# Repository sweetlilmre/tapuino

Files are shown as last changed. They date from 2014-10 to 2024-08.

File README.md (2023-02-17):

# Tapuino

This project is now in maintanence mode and has been superseeded by the [Tapuino Next](https://github.com/sweetlilmre/TapuinoNext)

However amazing people keep building this version and adding value (see the [3D printable enclosure below](#3d-printable-enclosure))

Limited support can be found in the following Amibay forum [Amibay](https://www.amibay.com/threads/tapuino-the-20-c64-tape-emulator.64874)

## The $20 C64 Tape Emulator

Details can be found on my blog: http://www.sweetlilmre.com

The FAQ and other docs can be found on the wiki: https://github.com/sweetlilmre/tapuino/wiki

A really nice board design can be found here: https://github.com/arananet/tapuinomini1.03

And a write up here: http://arananet-net.kinja.com/tapuino-1-03-mejorando-el-tapuino-mini-1788202676

These schematics are also provided in the "layout" folder as a convenience. 

Portions of this code are copyright by their respective owners:

 * PetitFatfs: Chan: http://elm-chan.org/fsw/ff/00index_p.html
 * I2C code: Peter Fleury <pfleury@gmx.ch>  http://jump.to/fleury
 * LCD code: conversion of the Arduino code apparently by DFRobot? (converted to C by me)

## 3D printable enclosure
by @fabriziofiorucci

A [3D printable enclosure](CAD) designed with Fusion 360 is available for download as .stl files

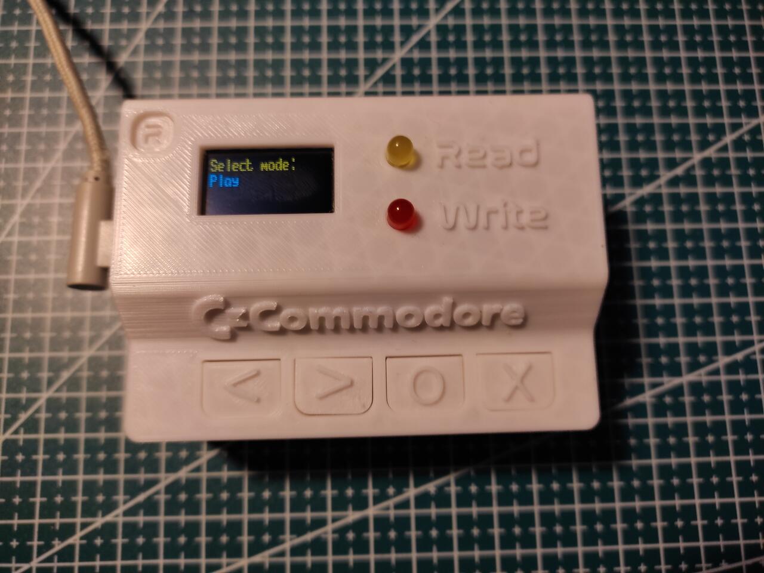
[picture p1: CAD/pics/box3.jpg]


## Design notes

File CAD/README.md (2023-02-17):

Tapuino 3D printable enclosure
==============================

This is a 3D printable enclosure designed with Fusion 360. It can be printed using PLA using:

- 3 walls
- 0.1mm layer height
- Supports for the top section and the C=64 connector lid



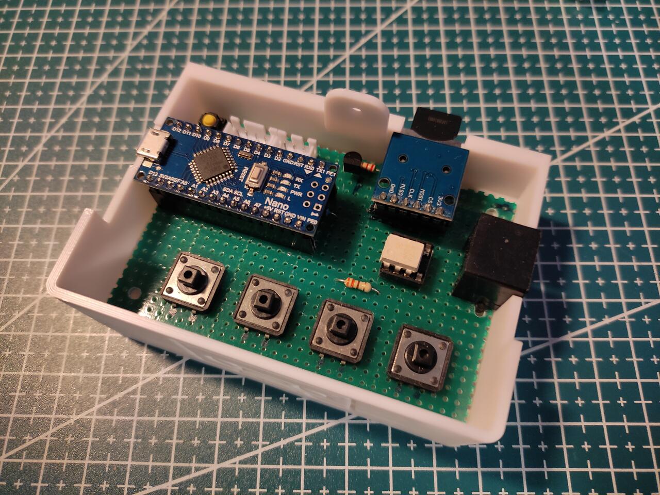
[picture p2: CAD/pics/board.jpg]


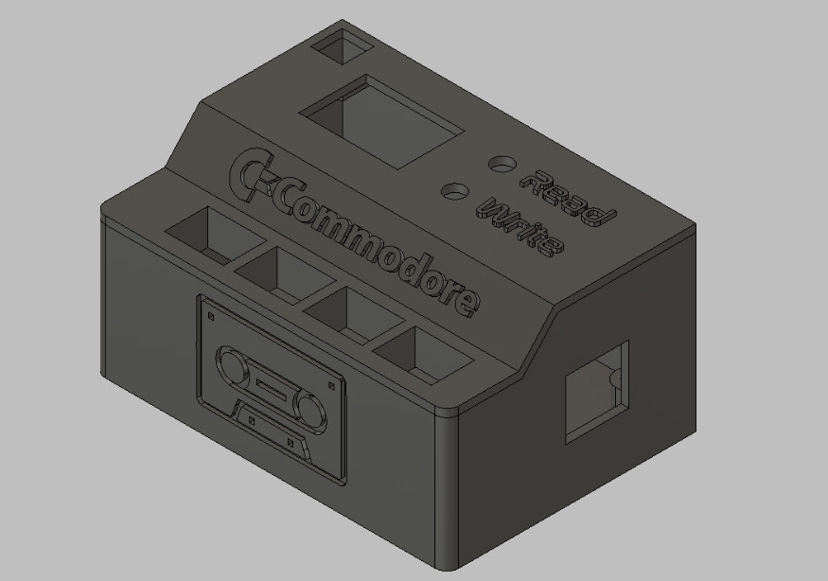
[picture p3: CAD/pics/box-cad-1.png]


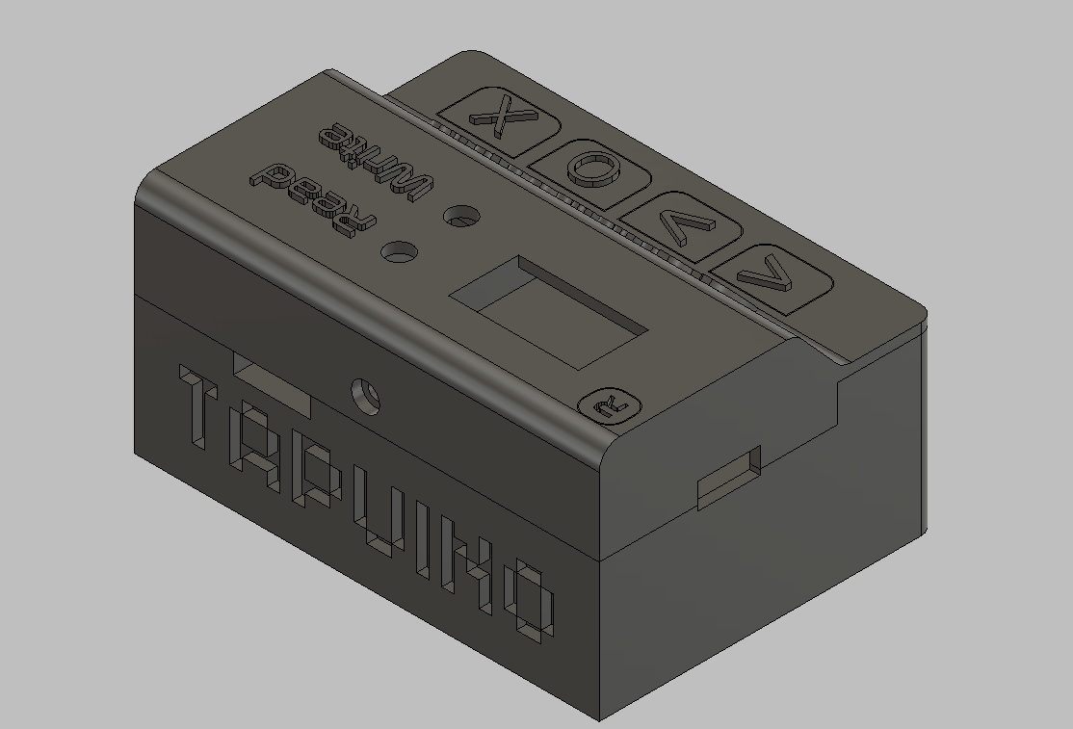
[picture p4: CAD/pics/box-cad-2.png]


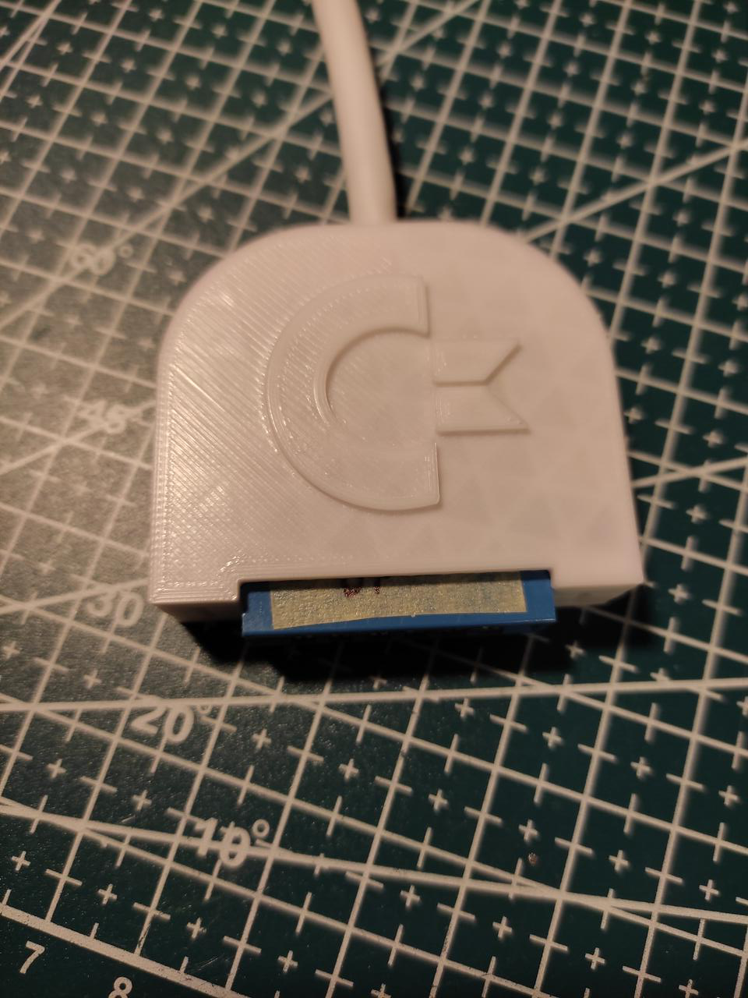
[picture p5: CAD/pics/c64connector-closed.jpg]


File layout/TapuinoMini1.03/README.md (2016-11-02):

# tapuinomini1.03

TapuninoMini 1.03 based on the design of OzayTuray - Original design by Peter Edwards ( sweetlilmre ).

A redesigned version of the Tapuinomini with built in buttons and connector on the PCB.

A step by step build process can be found on my blog:
http://arananet-net.kinja.com/tapuino-1-03-mejorando-el-tapuino-mini-1788202676

2016 -@edu_arana

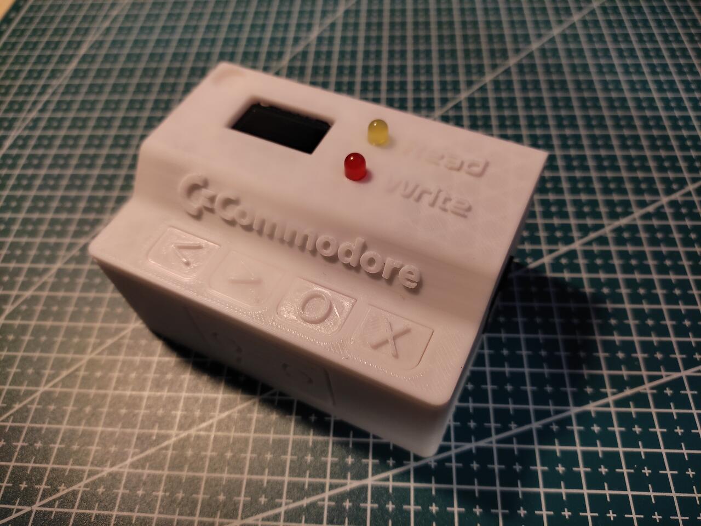
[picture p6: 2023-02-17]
CAD/pics/box1.jpg

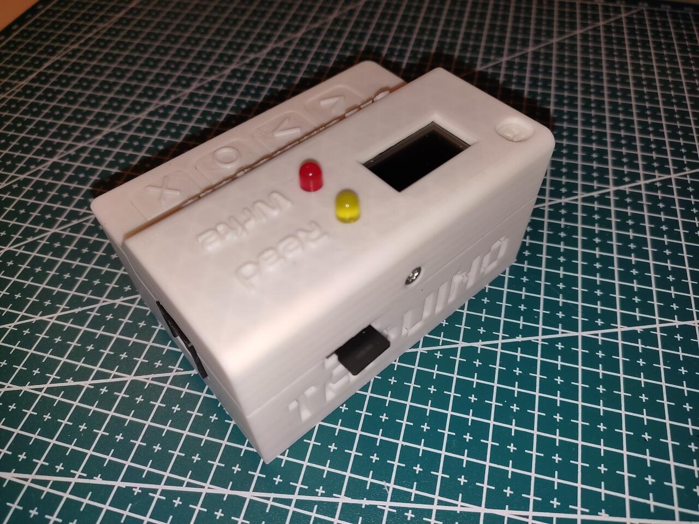
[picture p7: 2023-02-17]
CAD/pics/box2.jpg

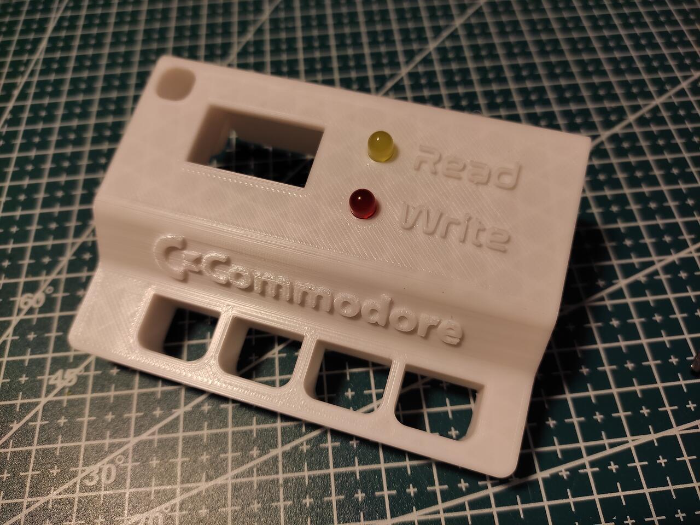
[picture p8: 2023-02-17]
CAD/pics/top.jpg

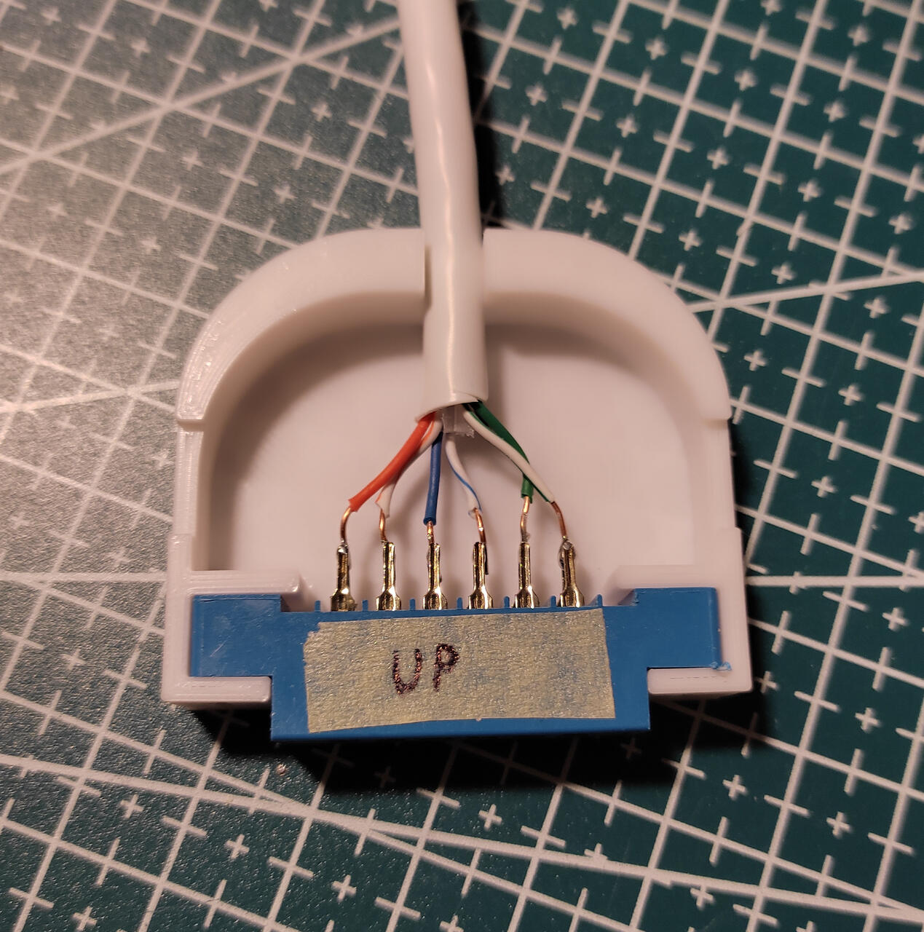
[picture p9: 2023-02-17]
CAD/pics/c64connector-open.jpg

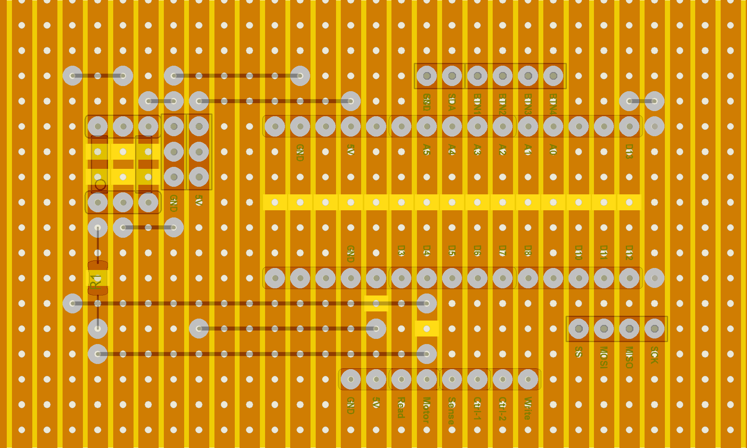
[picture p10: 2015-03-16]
layout/tapuino-main-bottom-r2.png

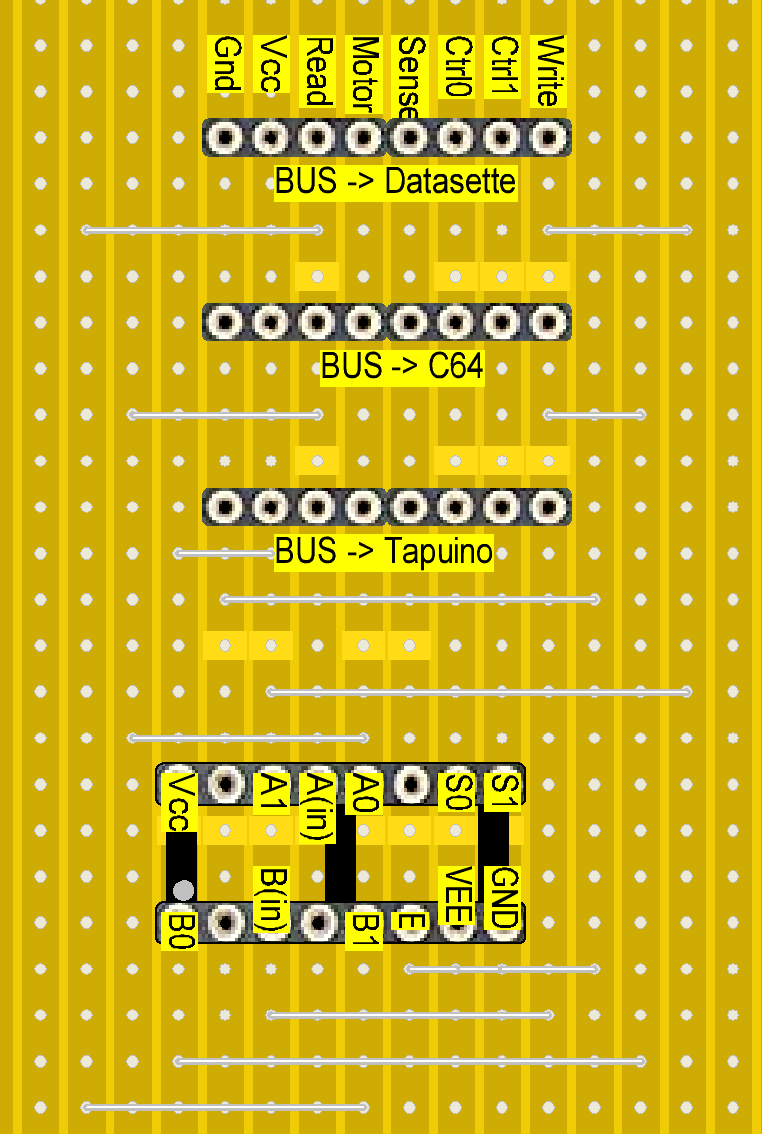
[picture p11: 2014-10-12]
layout/tapuino-mux-board-r2.png

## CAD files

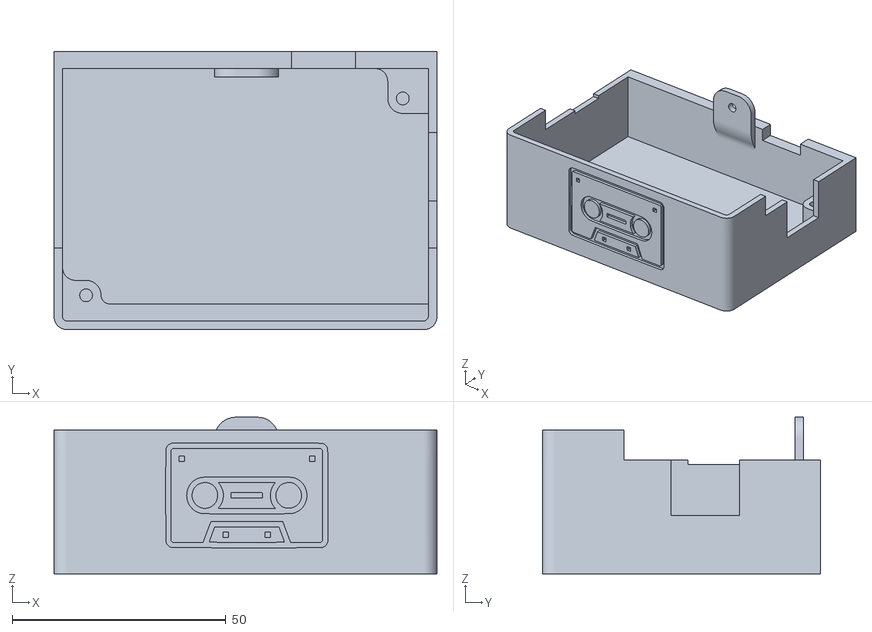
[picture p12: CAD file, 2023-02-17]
CAD/Main body.stl
89.5 x 65.0 x 36.6

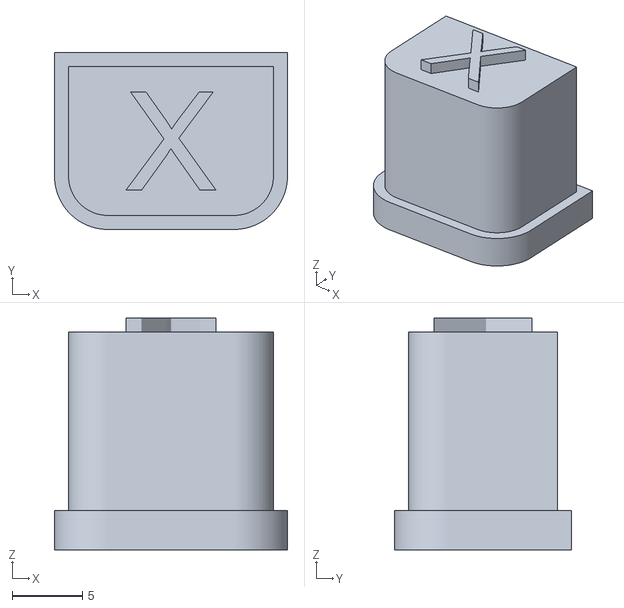
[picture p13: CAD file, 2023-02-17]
CAD/Key 4 - Cancel.stl
16.6 x 12.6 x 16.5

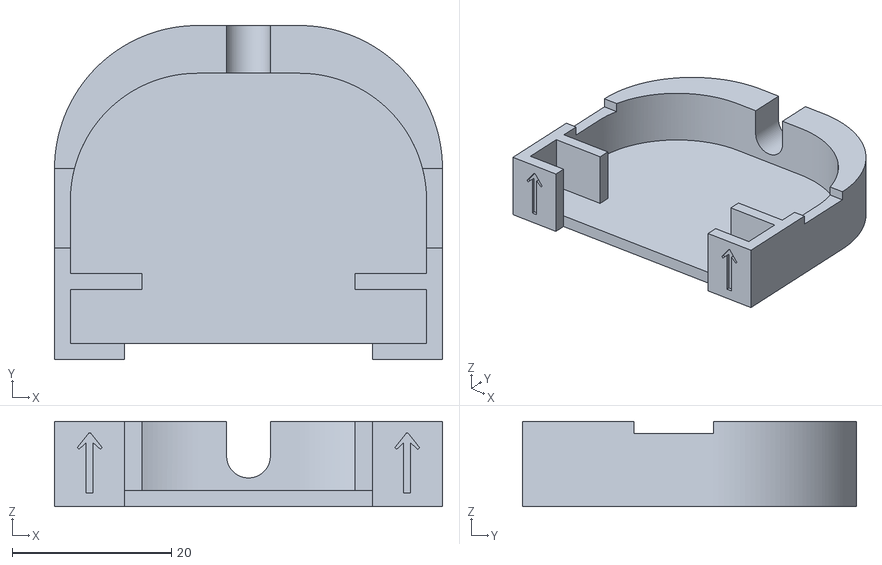
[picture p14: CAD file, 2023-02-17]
CAD/C=64 Datassette connector - base.stl
48.8 x 42.0 x 10.7

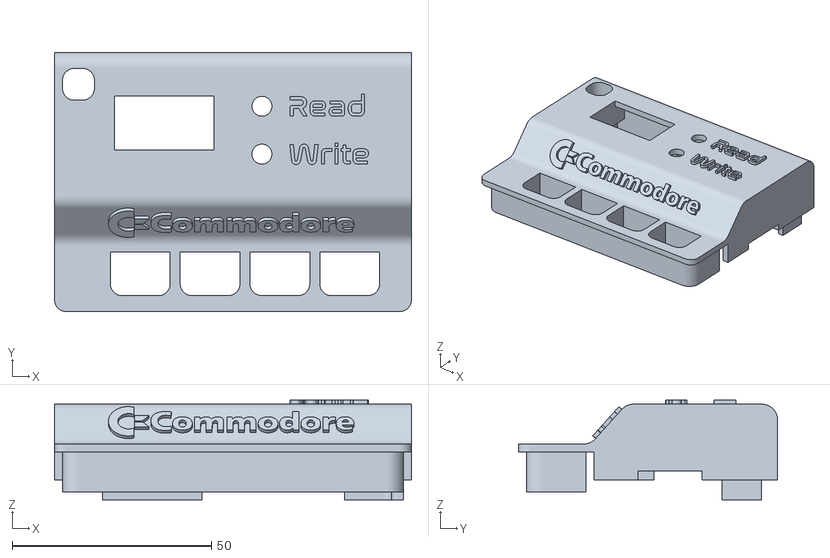
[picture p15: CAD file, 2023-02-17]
CAD/Top section.stl
89.5 x 65.0 x 25.0

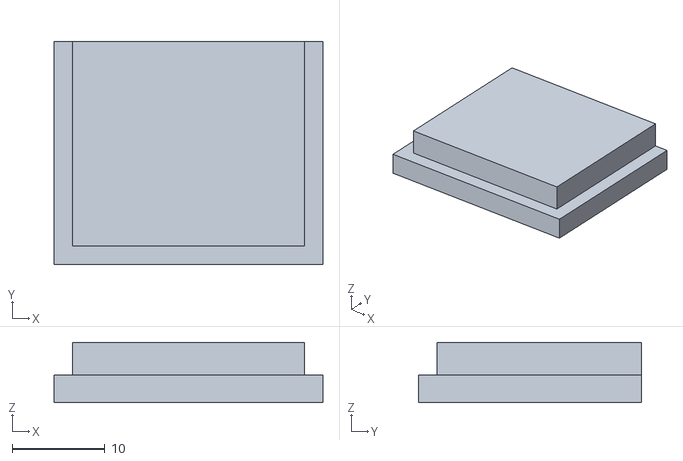
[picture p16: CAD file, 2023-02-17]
CAD/Display lid.stl
29.0 x 24.0 x 6.50

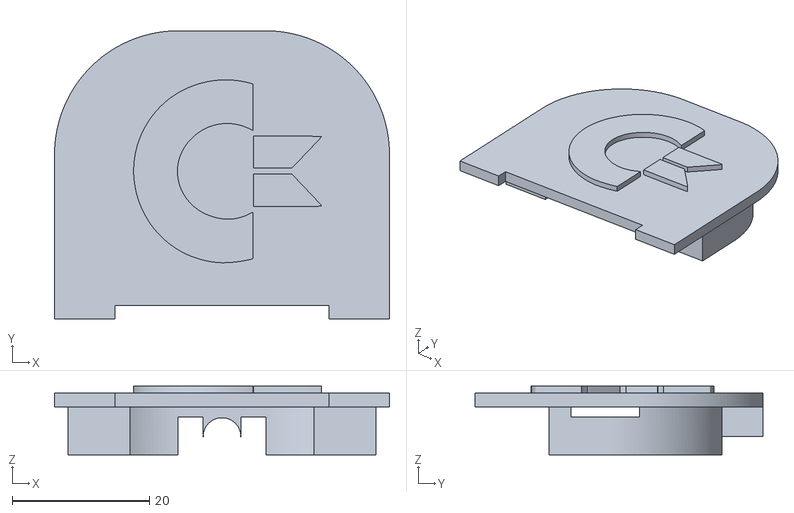
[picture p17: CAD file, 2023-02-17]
CAD/C=64 Datassette connector - lid.stl
48.8 x 42.0 x 10.00

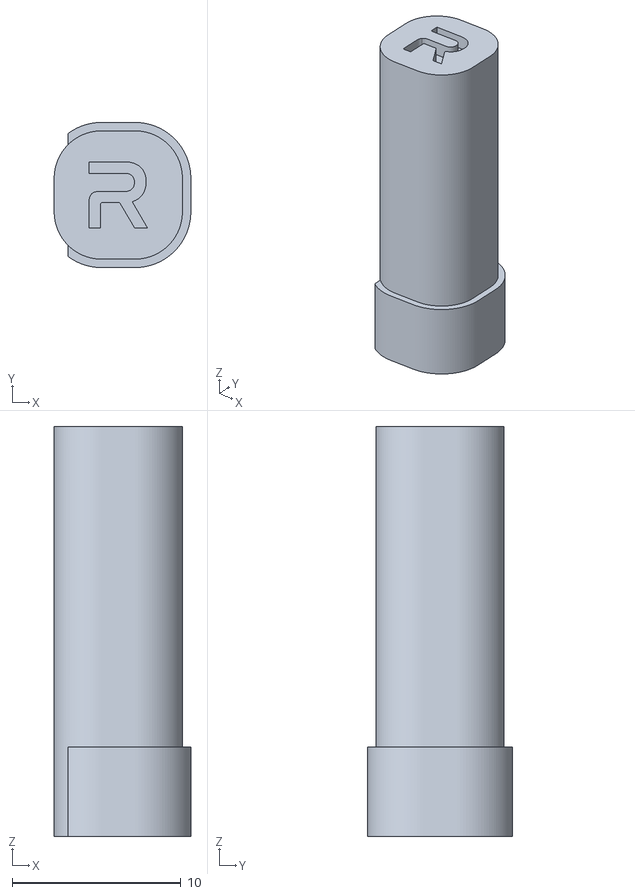
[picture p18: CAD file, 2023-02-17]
CAD/Reset button.stl
8.10 x 8.60 x 24.3

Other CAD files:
CAD/Key 1 - Left.stl
CAD/Key 3 - Select.stl
CAD/Key 2 - Right.stl

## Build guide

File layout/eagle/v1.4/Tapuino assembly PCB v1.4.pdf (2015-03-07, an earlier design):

# ASSEMBLY GUIDE FOR TAPUINO PCB V1.4 in PP9 BOX

v1.0

# BY spcbm

Thanks to all for your confidence in the Project, specially to sweetlilmre.

# PLEASE BE EXTREMLY CAREFUL TO AVOID

INJURY.

This is how I did the assembly, you may have a better way to do, just use it as a help.

Before starting, this PCB has the holes 2.8mm diameter, so you may need to make the holes 3mm for standard M3 screws and standoffs. If you plan to use the recommended PP9 box you will need to do the following:

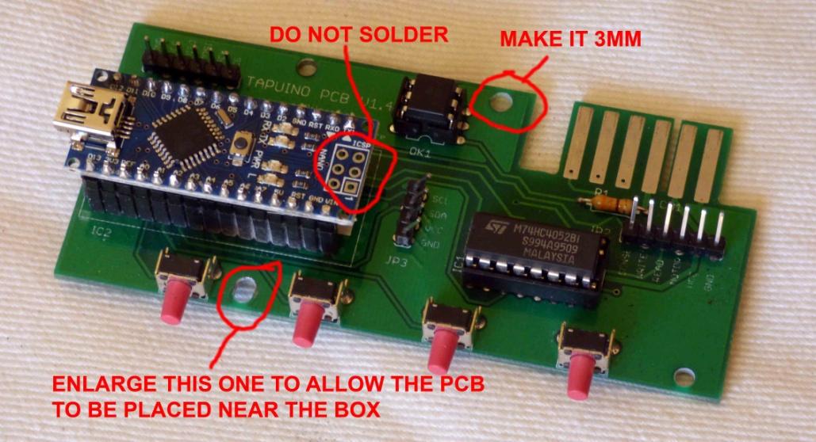
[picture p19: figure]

Solder all the components to PCB. Be carefull to align the buttons.

Do not solder the 6 pin header on Arduino or it will touch the LCD later.

If possible do not use socket for it, you will have more room for LCD and cables.

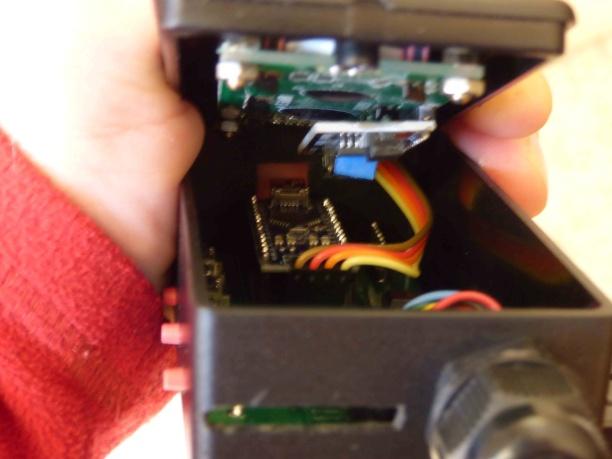
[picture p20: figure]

Drill the holes for LCD on the cover, you can use the template.

3mm drill for the 4 screws and 6mm drill for the rectangular hole.

I used wood drill that is OK for plastic also.

Verify your LCD to have the same layout before drilling. You may want to place LCD a little up instead of centered to avoid the I2c board touching the arduino.

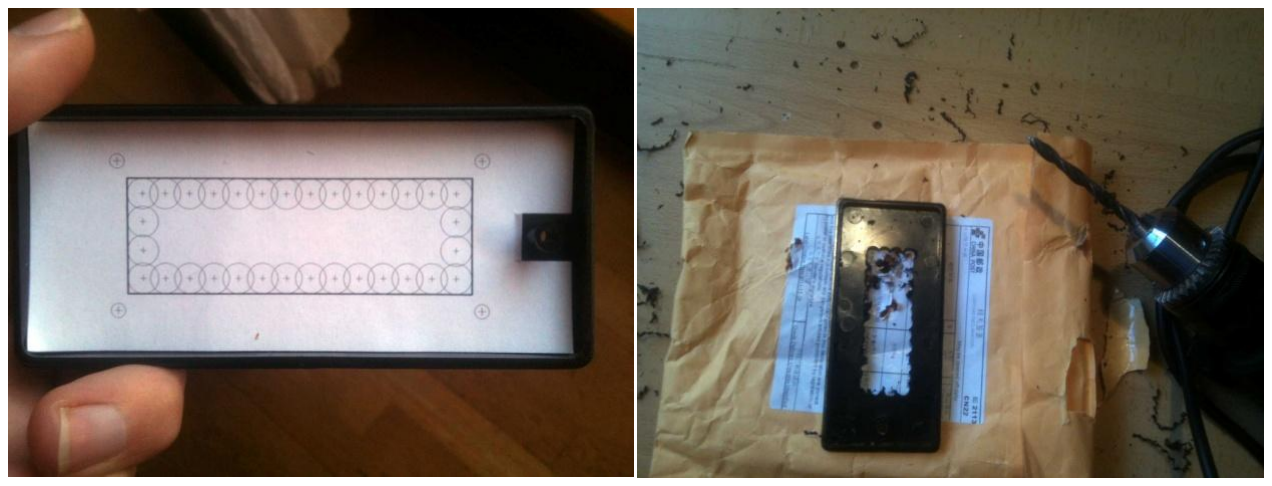
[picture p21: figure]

After a bit of sanding

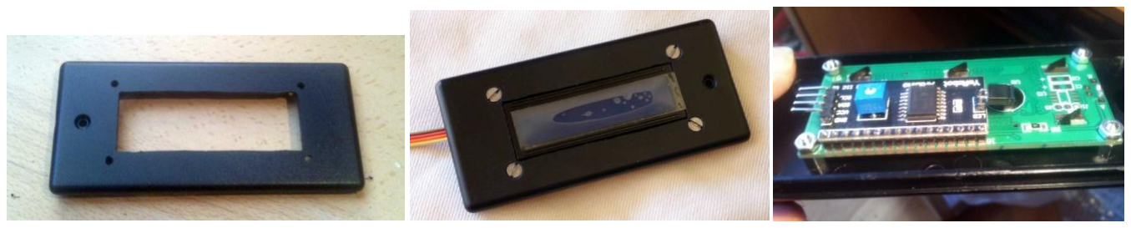
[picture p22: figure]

You need to countersink the 4 holes, use a 6mm drill (not for wood now)

If you do not have a stationary drill, do it with your hands, otherwise you may make a 6mm drill.

Using 4 standoffs M3 male-female, nuts and very short screws and you are done with LCD.

Time to make drills for the buttons, use the template and a 4 or 4.5mm drill.

Check carefully allignament before drilling.

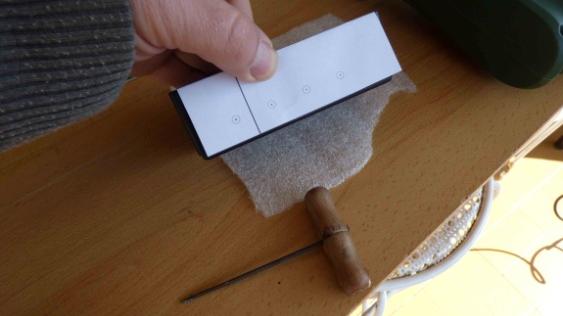
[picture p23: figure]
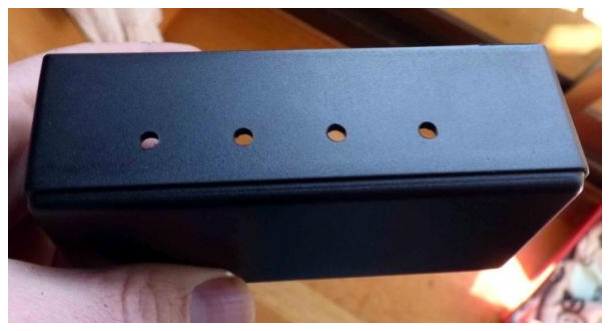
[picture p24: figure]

The PCB should fit now inside the box, put the 3mm sheet metal screw thread | near the first
button and thread it into the plastic standoff of the box. Then mark the hole position for a new standoff you need to add.

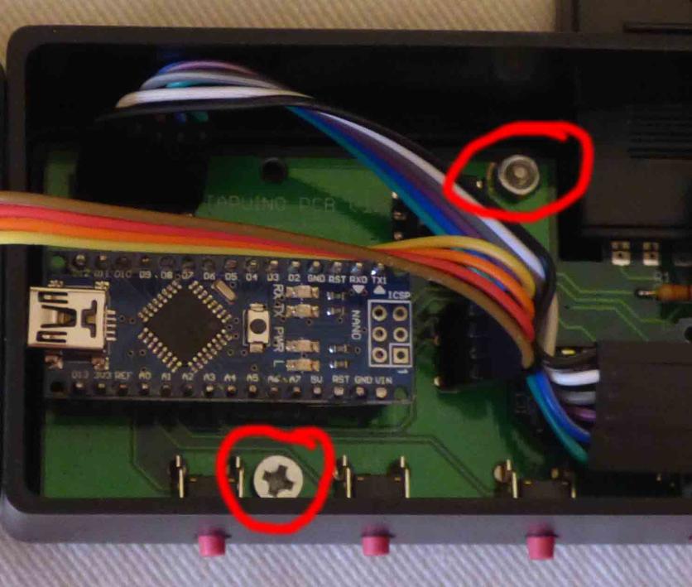
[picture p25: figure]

As the standard standoffs are 5mm just add 2 washers to reach 6mm that is the height of the plastic one of the box, just to keep PCB horizontally.

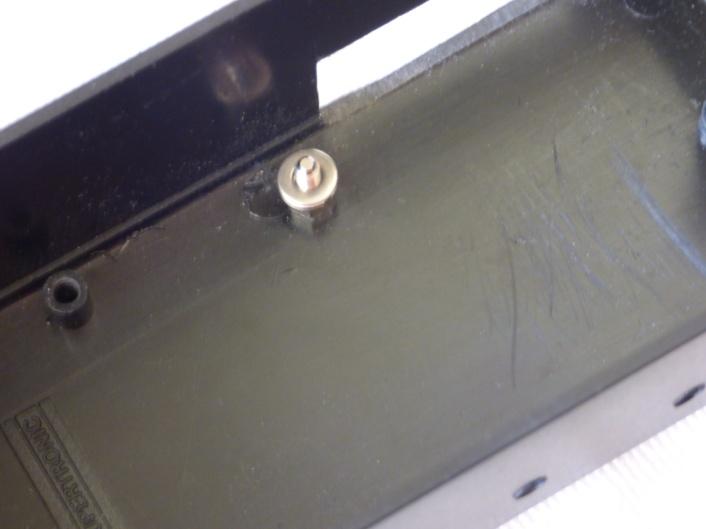
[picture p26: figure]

Now make the holes for datassette connector and USB . Always check before drilling.

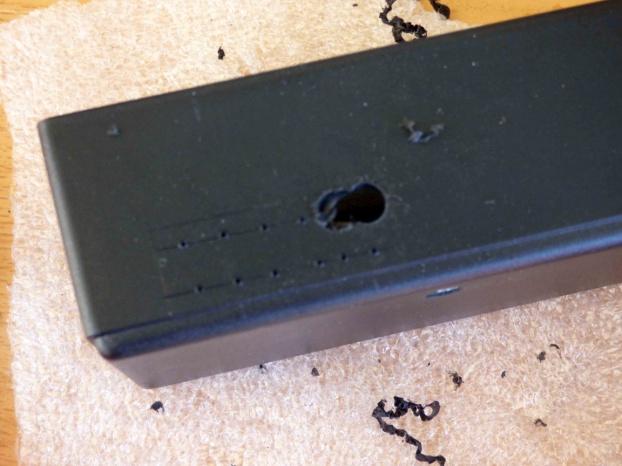
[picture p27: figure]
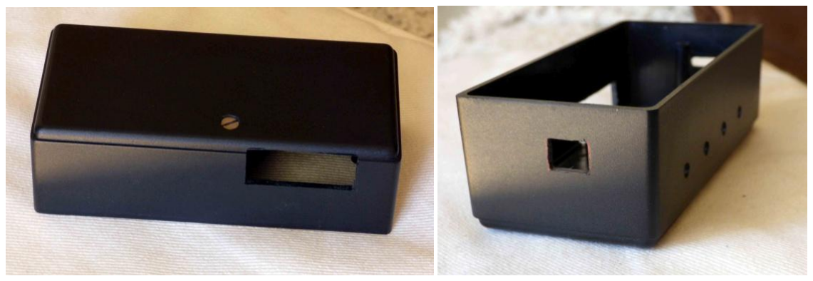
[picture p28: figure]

I’ve found this place to put micro SD shield. You need to make a small notch in the PCB

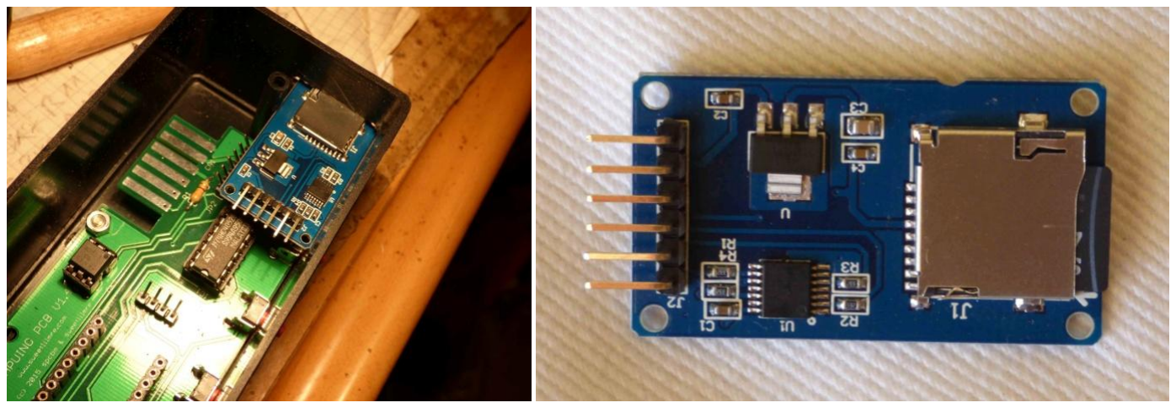
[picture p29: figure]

Verify that you can insert and extract SD card before making the notch.

Then you can make the hole, I used 3mm drills for this.

You can put a piece of plastic under SD shield to avoid shortcircuits.

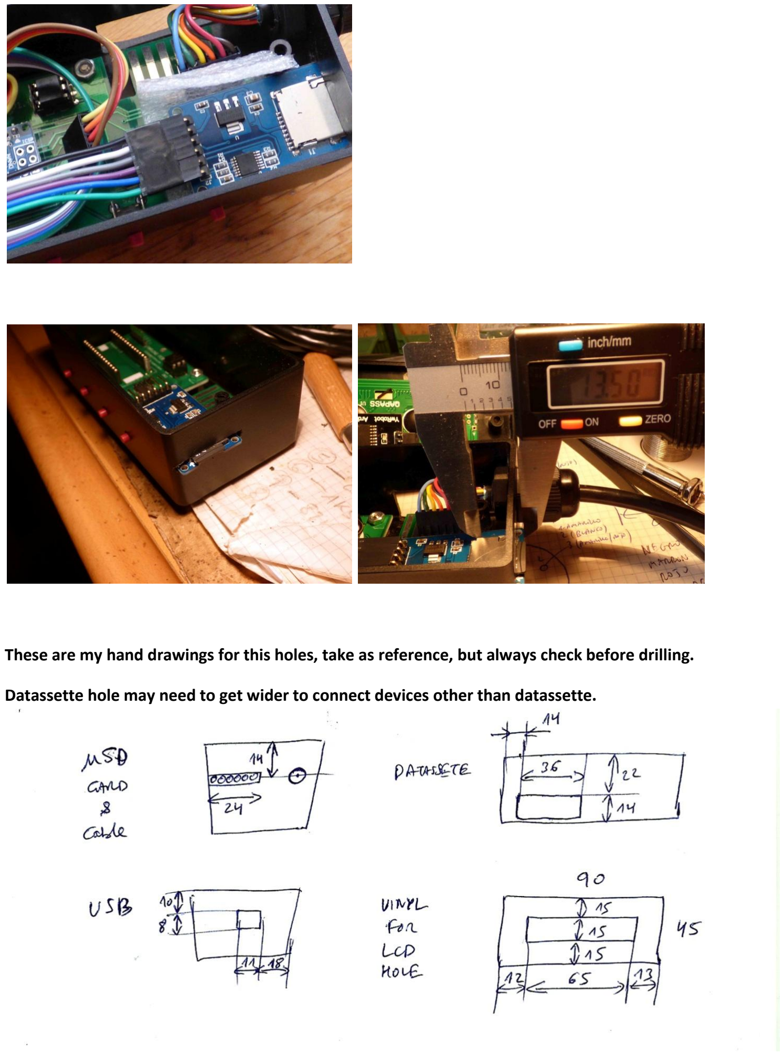
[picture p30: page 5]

These are my hand drawings for this holes, take as reference, but always check before drilling.

Datassette hole may need to get wider to connect devices other than datassette.

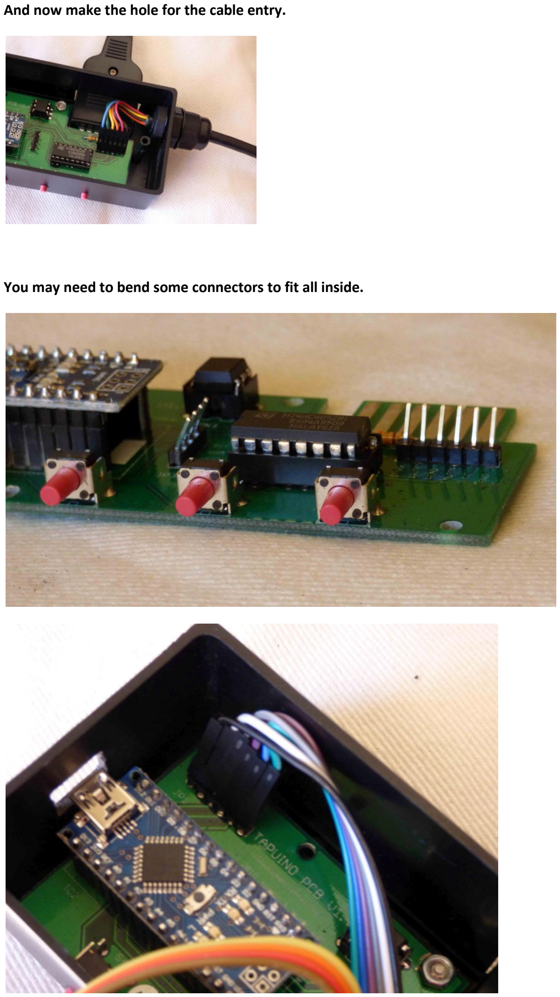
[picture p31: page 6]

And now make the hole for the cable entry.

You may need to bend some connectors to fit all inside.

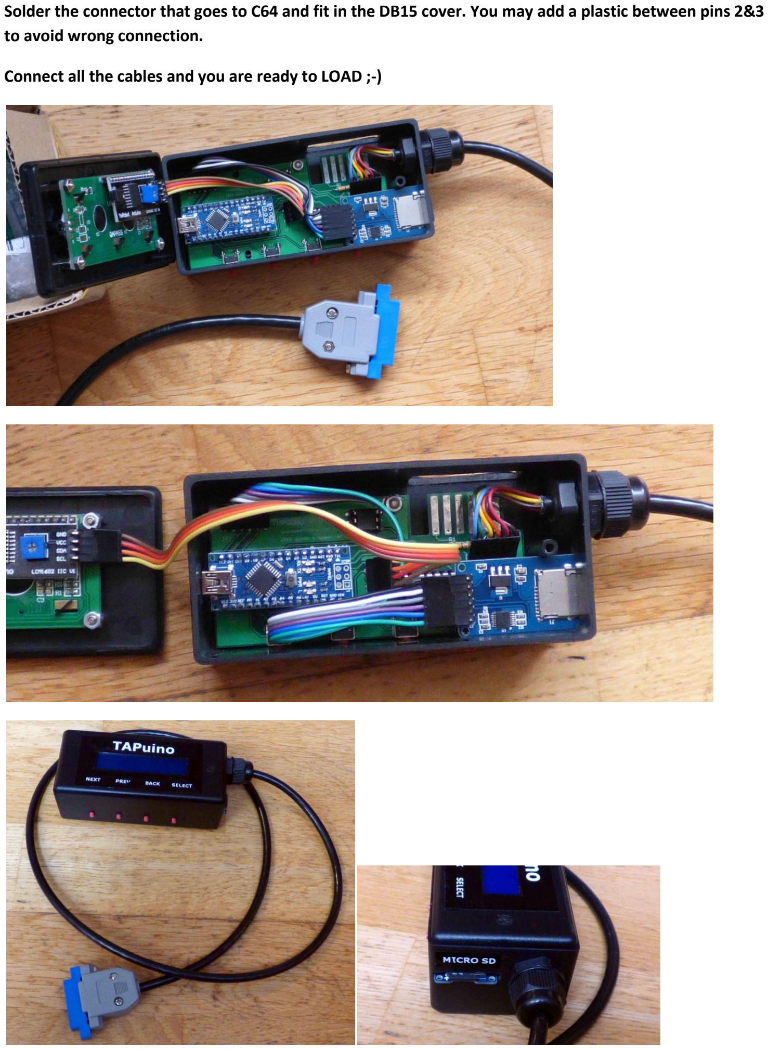
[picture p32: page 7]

Solder the connector that goes to C64 and fit in the DB15 cover. You may add a plastic between pins 2&3 to avoid wrong connection.

Connect all the cables and you are ready to LOAD ;-)

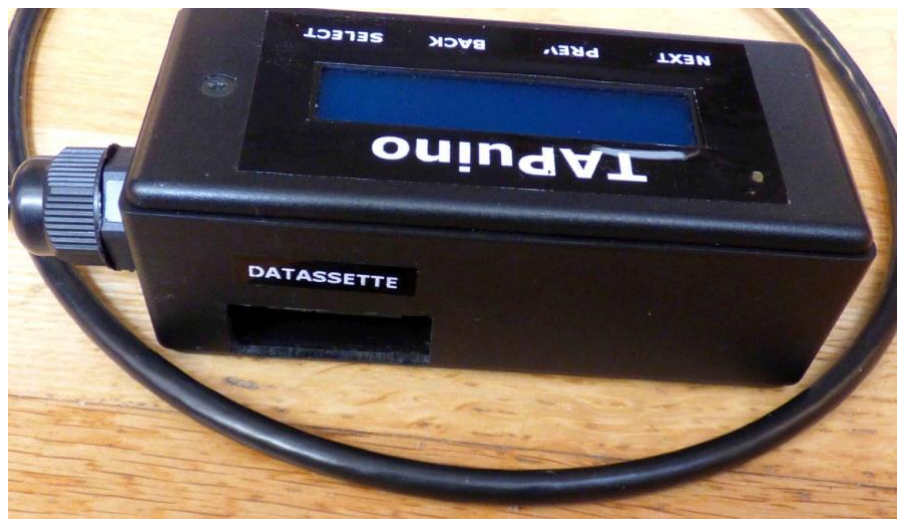
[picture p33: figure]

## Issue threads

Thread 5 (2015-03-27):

Recording does not work on an SD card with no files or folders

sweetlilmre, 2015-03-27:
Part of the init code checks to see that there are a non-zero number of files or folders on the SD card and fails if this is not the case. This prevents recording on new cards.

sweetlilmre, 2015-03-27:
Fixed in commit: 65e503846d91745694a79337717c09b2bd39a0f7

Closed 2015-03-27.

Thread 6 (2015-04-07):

6 buttons

Sven1973, 2015-04-07:
At this moment are only 4 buttons implemented in software. For using a original housing of 1531 it will be nice to implement 2 more buttons.
RECORD for switching/toggeling recordmodes
EJECT for toggeling directories (as example)

juri74, 2015-04-16:
i would not add more buttons because there are already lot of tapuino players that would have to redo all work, i will add support for 6 buttons in a different manner:

2 buttons pushed togheter; example: play and stop pushed togheter will ats like a eject, unloading tape and put you on the root of sd card
play + forward acts like record.. so you can put more microswitches but mantaining the compatibility for 4 buttons layout.
one interesting function however would be PAUSE, since there are lot of tapes with multiple programs on it, in this way could be possible to pause the tape, reset c64, type load"" and finally unpause the tape to continue loading...
this could be implemented with the "select" button: pressing it during tape loading will put pause on, pressing again will put pause off.

Sven1973, 2015-04-17:
yes, your solution with two Buttons pushed together sounds plausible.
And it would work for me too, just a question of wiring...
thats a good idea !

sweetlilmre, 2021-09-13:
closed stale.

Closed 2021-09-13.

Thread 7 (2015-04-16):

Save led, piezo to "listen to" the tape

juri74, 2015-04-16:
Could be possible to implement:
1) a red led that will lit when saving in progress?
2) a piezo that play the music? :D for ability to listen loading/saving maybe turnable on/off in Options menu ;)
i splitted the pause from led & piezo, since there is an hardware solution is better use it to save program space.. however a led connected to D13 (if isn't used for other things) could be useful and shouldn't use much program memory i think (D13 is already connected to a led on almost all arduinos) :)

sweetlilmre, 2015-04-17:
There are hardware solutions available for something similar to the piezo via ozayturay's board (provides LEDs that are transistor driven for SAVE / LOAD).
Please could you break this up into separate issues? The save LED could be handled fairly easily via code (just add an output) etc. so tracking these separately is better.

sweetlilmre, 2015-05-24:
The save LED function will be added with the release of the 1.7 hardware and controlled via software, I'm just waiting for the boards so that I can verify this.
The piezo switching is another story and would require hard ware support so I don't think this is going to happen.

juri74, 2015-05-25:
Thank you for update, i have an idea on how doing piezo support with minimal effort, i think arduino should provide an "activation signal" then it will be ANDed with the tape read or tape write signal, finally the output pin of the AND chip will drive a piezo. i have to wait the 1.7 board too and some parts for testing :) i lost track of available pins, is there one free? thanks
Juri

sweetlilmre, 2015-08-16:
Save LED support has been added to the code base, piezo is hardware supported on 1.7.

Closed 2015-08-16.

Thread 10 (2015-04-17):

Pause function

juri74, 2015-04-17:
Could be possible to implement a pause button? example: using the "select" button during tape play, pressing it will pause tape and pressing it again will unpause tape.
this would be useful with tapes that have more programs/games in it

sweetlilmre, 2015-05-24:
How common is this? A higher priority would be proper seek control for multipart games, which would probably provide you with what you needed for this feature.

sweetlilmre, 2015-05-25:
I've added experimental support for this in the pause-func branch. Test and I'll think about merging it into master as a temporary fix until proper play control is added

sweetlilmre, 2015-06-05:
This is now in master

Closed 2015-06-05.

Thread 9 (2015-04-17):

C16 / Plus 4 halfwave playback support

sweetlilmre, 2015-04-17:
Adding support for format 2 (halfwave) TAP playback would extend the reach of the Tapuino to these platforms.

juri74, 2015-04-17:
i tested some v2 (and v1) c16 tap with tapuino without success. when i press select when displaying a tap file name nothing happens (if the file name is scrolling on display the scroll position is resetted to beginning of text every time i press select button)

sweetlilmre, 2015-04-17:
How recent is the code you have flashed? There was a bug where the C16 TAP file would have been considered invalid but the error would not have been displayed making it look like nothing had happened. This code has changed and C16 support was added for headers a few versions back.
Can you confirm or flash the latest and try again?

juri74, 2015-04-18:
hello! updated to the most recent version and now it recognize some files (some give INVALID TAP)
i sent you a report email with attached a zip file containing the TAP files i tested.

sweetlilmre, 2015-04-21:
Hi. I've updated the source with some fixes, please test when you are back in town.

juri74, 2015-04-21:
hello
i will test asap :D

Il 21/04/2015 16:47, sweetlilmre ha scritto:
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

---
Questa e-mail è stata controllata per individuare virus con Avast antivirus.
http://www.avast.com

juri74, 2015-04-25:
I made further test with updated firmware, actually i had a problem only with one file on 19 files tested, i'm going on testing, but it does appear the last firmware update really fixed lot of tap loading problems :)

sweetlilmre, 2015-05-24:
This code is in now and I have a C16 on order so I will hopefully be able to look into this in more detail once I have the machine :)

sweetlilmre, 2021-09-13:
closed

Closed 2021-09-13.

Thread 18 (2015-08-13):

Recordings are finalized when motor stops

Quagliarulo, 2015-08-13:
Hello, I have a proposal. Tapuino shouldn't finalize a recording when the motor is turned off. It should just wait for either the motor to be started again or the user to press "stop". I'm playing with the Freeload mastering tool. It loads each file from disk and then stores it on tape. But it doesn't work with Tapuino, because when the program stops the motor and reads from disk, the recording is finalized.

sweetlilmre, 2015-08-16:
I have added a branch to test this as a new feature.
Under the options menu there is an "Auto Finalize" option. If this is set to zero then the recording will continue until the ABORT button is pressed. Please test and let me know if this addresses the issue.

Quagliarulo, 2015-08-17:
Hello and thank you for your time. Your modification addresses the issue. Here's a freeload game mastered with Tapuino:
https://drive.google.com/file/d/0Bzow0Exbi92AeW5IQ2RHcUFyNnc/view?usp=sharing

Some thoughts:
- A couple of times I had lockups while browsing through the menus, with a strange string:
https://drive.google.com/file/d/0Bzow0Exbi92AeXdZRlJjUzl5Ylk/view?usp=sharing
I guess this might be due to some "unexpected" button presses I made (I connected my button panel incorrectly and wouldn't bother to fix it). I'll try to replicate it.
- "Auto di finalizzazione" should become "Auto finalizza" (how do I know? I'm Italian :)
- I think the spinning character shouldn't spin when the motor is off

Quagliarulo, 2015-08-17:
I just noticed there are very long pauses between freeload blocks. This doesn't happen with Vice (no pauses at all in that case). Gotta try with real tape.

Quagliarulo, 2015-08-17:
Real tape mastered and dumped with MTAP. Tapclean says pauses between Freelod blocks are either 1.0556 or 1.0759 seconds, so I'm afraid something doesn't work.

sweetlilmre, 2015-08-19:
I've added another commit to try and address the pausing issue as well as the menu bug introduced by the previous commit. Please test!

sweetlilmre, 2021-09-13:
closed due to inactivity

Closed 2021-09-13.

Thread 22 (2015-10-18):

Datassette calibration function

Quagliarulo, 2015-10-18:
Very simple: a function which samples pulses and shows a percentage or something like that. It may work like this:
- Capture all the pulses occurring in a given time frame and store them only once each. If the number of unique pulses reaches a given maximum, assume no data or very bad alignment.
- See how many different pulses we got. In a hypothetical perfectly aligned tape, we wouldn't get less than 2 or 3 pulselengths in total. The more pulselengths, the worse the alignment. So at this point, we may show a percentage or some description such as "Good", "Bad", and so on.

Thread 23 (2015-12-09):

Rotary Encoder

Cino2424, 2015-12-09:
I would prefer a rotary encoder support instead of 4 buttons.
It would be easier to create a smaller case or to build it into the c64 case himself.

sweetlilmre, 2016-06-13:
Support for this feature has been added

Closed 2016-06-13.

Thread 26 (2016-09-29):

Compiler warnings and NL language

Squirrel61, 2016-09-29:
Recently, I brought new life into an old love and acquired a used C64. Of course, I wanted to know what could be done with such an old system using new technology and discovered your Tapuino project.

Currently I'm still waiting for some of the parts needed, but I already had an Arduino Nano V3 which I programmed with the Tapuino firmware.

When compiling with the current Arduino IDE 1.6.12, 4 warnings where issued. I don't know if this is a result of compiler changes in the recent IDE or if they already where present when you created the project. I also don't know, when the warnings already where present when you created the project, if they where left there on purpose. However, they're easy to clear.

This is the list of warnings:

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

To correct, I changed tapuino.h as follows:
`#ifndef TAPUINO_H
# define TAPUINO_H
# include "ff.h"

void tapuino_run();
void record_file(char\* pfile_name);
int play_file(FILINFO\* pfile_info);
uint32_t get_timer_tick();
void save_eeprom_data();

extern volatile uint8_t g_invert_signal;
extern volatile uint16_t g_ticker_rate;
extern volatile uint16_t g_ticker_hold_rate;
extern volatile uint16_t g_key_repeat_next;
extern volatile uint16_t g_rec_finalize_time;
extern volatile uint8_t g_rec_auto_finalize;
extern uint8_t g_machine_type;
extern uint8_t g_video_mode;
extern volatile uint8_t g_is_paused;
# endif`

This makes the project compile without warnings. However, since I've not been able to test it (still waiting for some parts), I don't know if I possibly broke something.

Furthermore, I've also created a Dutch menu language file. But have to check on the working hardware if all messages are meaningful before I'll share them.

sweetlilmre, 2016-09-29:
Good catch. Seems I missed that in the header, there should be no untoward issue with fixing this that I can think of. Please submit a pull request to fix this if you could and when you have finished with the Dutch translation, submit another and I will action.

Squirrel61, 2016-10-04:
I tried to submit a pull request but actually, I have no idea if I succeeded. Github is totally new to me so I might have done something wrong. Excuse me if I screwed up the main project ;)

Closed 2017-12-25.

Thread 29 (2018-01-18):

Porting to Mega 2560 : problem after "found" message

dashiad, 2018-01-18:
I'm mixing your code with some iec code i've developed, to have both tape and disk support.
As the code for the disk may grow (a lot), and i've added a touchscreen, i've chosen a mega 2560 as target device.
But i'm getting a bit stuck with a problem: the load starts ok, but, after the "found xxx" message appears, looks like somewhere is not detecting the play button as pressed anymore: after the "found" message, i get a "LOADING" and then,again, "PRESS PLAY ON TAPE".

Any idea of what may be happening? (I ported the code to a mega 1280 without problems)
My pin assignment is (even pins from 35 to 41):

// port definitions, change for different wiring
#define SENSE_PORT          PORTG
#define SENSE_DDR           DDRG
#define SENSE_PIN           0
#define SENSE_ON()          SENSE_PORT &= ~_BV(SENSE_PIN)
#define SENSE_OFF()         SENSE_PORT |=  _BV(SENSE_PIN)

#define TAPE_READ_PORT      PORTC
#define TAPE_READ_DDR       DDRC
#define TAPE_READ_PIN       0
#define TAPE_READ_PINS      PINC
#define TAPE_READ_LOW()     TAPE_READ_PORT &= ~_BV(TAPE_READ_PIN)
#define TAPE_READ_HIGH()    TAPE_READ_PORT |=  _BV(TAPE_READ_PIN)

#define TAPE_WRITE_PORT     PORTG
#define TAPE_WRITE_DDR      DDRG
#define TAPE_WRITE_PINS     PING
#define TAPE_WRITE_PIN      2

#define MOTOR_PORT          PORTC
#define MOTOR_DDR           DDRC
#define MOTOR_PIN           2
#define MOTOR_PINS          PINC
#define MOTOR_IS_OFF()      (MOTOR_PINS & _BV(MOTOR_PIN))

juri74, 2018-01-19:
that's very curious.
have you tried different taps? have you tried to load the same tap with a real datassette?
that sound very strange because as soon as "found" message appear, when you press space or commodore key even if you have stopped the datassette, the c64 should behave like if the play button is pressed (even if it isn't)

dashiad, 2018-01-19:
I've been debugging a bit more.
What i've found is : tapuino thinks the tape has finished
(g_tap_file_pos == g_tap_info.length) (line 225 of tapuino.c).
Looks like something is messing with the timer, maybe the lcd code. I'll try using timer 3 instead 1 to see if that helps.

But at least i've a hint about what is wrong with my code, (of course, it's not tapuino's fault), so i'm closing the issue. Thanks for your help!

Closed 2018-01-19.

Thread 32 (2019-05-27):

Low memory warnings

gwiorek, 2019-05-27:
Is this normal?  First time working with the code part of tapunio and a bit rusty with the Arduino but seems to be a big possible issue should you have more the a few tape files to track.

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

Trying to reimage my mini as it jsut stopped working and trying to resurrect it as it looks like the nano may be still working but lost the software.

sweetlilmre, 2019-05-27:
This is fine, the sketch is just almost at max capacity for the nano.

gwiorek, 2019-05-27:
Thanks!  

-----Original Message-----
From: sweetlilmre <notifications@github.com>
To: sweetlilmre/tapuino <tapuino@noreply.github.com>
Cc: gwiorek <gwiorek@aol.com>; Author <author@noreply.github.com>
Sent: Mon, May 27, 2019 12:41 am
Subject: Re: [sweetlilmre/tapuino] Low memory warnings (#32)

This is fine, the sketch is just almost at max capacity for the nano.—
You are receiving this because you authored the thread.
Reply to this email directly, view it on GitHub, or mute the thread.

Closed 2019-05-27.

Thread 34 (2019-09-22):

The Max7219.h library

Therealjosephchrzempiec, 2019-09-22:
Hello i was looking at the code and say there is a Max7219.h in the arduino ino. But in your files you do not have have the libray there. I don't know that library either. I know the Max7219 chip is a input/output driver for leds. But yet somehow the code compiles with no problem even if i don't have that library. Strage!!

I never saw a code  compile with no errors with a missing library. Why is this?

Joseph

sweetlilmre, 2019-09-24:
Hi,

I don't see this in the .ino file?

Therealjosephchrzempiec, 2019-09-24:
I'm  sorry that was the sd2iec i was looking at my mistake.

sweetlilmre, 2019-09-24:
No worries :-)

Therealjosephchrzempiec, 2019-09-24:
I just tried tapuino for the first time tonight and went great
 I hand build my own becuase i cant afford to buy one. But it took me a while to figure out the wiring. Used a lot of jumper wires lol.

Closed 2019-09-24.

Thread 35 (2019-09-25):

Not a issue but I have a question

Therealjosephchrzempiec, 2019-09-25:
Hello you did a awesome Job on the tapuino for arduino. It works great, Thank you.  But i have a question have you looked into maybe doing the sd2iec? I know there out there  but not a arduino version.

Joseph

sweetlilmre, 2019-09-25:
The arduino doesn't have enough power to handle sd2iec.
I did look at it once. Better bet would be a cheap arm board

Therealjosephchrzempiec, 2019-09-25:
Hello thank you.  Is there a better way to get a message to you without taking up issues in here?

sweetlilmre, 2019-09-25:
Email? My username at Gmail.

Closed 2019-09-25.

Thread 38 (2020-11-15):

Possibe bug while reading the tape buffer?

dashiad, 2020-11-15:
Hello,
For a small project i'm working in, i want to refactor some code out of the interrupt handler, specially calculating the pulse lengths in the main loop. That would produce a mismatch between the number of bytes read from the file, and the number of pulses to fire, as "overflow" bytes need 4 bytes if the version is not 0.
So, theoretically,  to correctly convert  X bytes from the file to pulses, i need to be sure the buffer grows, if necessary, up to X+3 bytes, in case the last byte read is 0x00 (overflow byte), and version is not 0.
So i went to check how this is managed in tapuino, but (correct me if i'm wrong) looks like a fixed chunk of  FAT_BUF_SIZE bytes are read, and the isr code is supposing that, if a 0x00 byte is found, the other 3 bytes do exist in the buffer
```
 if (tap_data != 0) {
          g_pulse_length_save = tap_data * g_cycle_mult_8;
        } else {
          g_pulse_length_save =  (unsigned long) g_fat_buffer[g_read_index++];
          g_pulse_length_save |= ((unsigned long) g_fat_buffer[g_read_index++]) << 8;
          g_pulse_length_save |= ((unsigned long) g_fat_buffer[g_read_index++]) << 16;
         ...
   }
```
So, if a 0x00 byte is found at g_fat_buffer[FAT_BUF_SIZE-1], arent those lines accessing unitialized memory?

sweetlilmre, 2020-11-16:
I think you are correct. Amazingly this doesn't seem to have caused a problem in real life. Even more so as the potentially out of bound bytes are the most significant values of the timing signal and random data could really skew the value.
The issue for me is that the buffer swapping and handling is tightly coupled to the buffer size and would require significant rework to fix. I really need to rewrite this codebase at some point to use a more modern mcu like an ESP.

sweetlilmre, 2020-12-01:
On further reflection this isn't actually a problem :)
The buffer that the data is read from is a 256 byte buffer, indexed by a byte-wide variable (g_read_index).
Think of the buffer as two 128 byte buffers joined together.
As the longer pulse lengths are computed 1 byte at a time, if the index is 255 it will overflow back to zero.
This is half of the story. What is happening outside of the interrupt is that the buffer index is monitored, as it moves to the 2nd half of the buffer, the first half is filled with an SD load and same as it moves to the first half.
This means that as long as the TAP data is valid, no uninitialized memory is accessed.

Closed 2020-12-01.

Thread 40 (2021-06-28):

Problematic connection with sense and real datassette

heneault, 2021-06-28:
From the schematic it seems the sense pin for both connector, c64 and real datassette, are tied together. However, the firmware only configure this pins as an output from the arduino perspective. That mean if a real datassette is plugged in, both datassettte and arduino will try to drive this signal, which is bad.

heneault, 2021-09-08:
Never mind, I just realized sense must be activated to have current to motor even in invert mode Also sense circuit inside real datassette is safe for that (plain ground)

Closed 2021-09-08.

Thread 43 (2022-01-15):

Questions about Tapuino functionality

lovrenco, 2022-01-15:
Hello.

First of all, thank you for this great little device. I bought mine from Edu Arana, some time ago, but tested it just few days ago.
https://github.com/arananet/Tapuino-Reloaded

I have some questions that others might find interesting as well:
1. Is there a PDF manual which describes all Tapuino functions and button combinations?
2. Is there a way to play T64 files directly from SD card on Tapuino?
3.  If I use some save state functionality by Replay cart and dump state of C64 on floppy to restore it later, can I manually set position on Tapuino at exact percent where it was before I dumped state? For example 75% of loaded TAP file (FW, RW I suppose)?

Sorry if this was asked before. Thank you.

sweetlilmre, 2022-01-17:
Hi there,

Thanks for your interest, to briefly answer your questions:

1.  Unfortunately not. If anyone feels like writing something up in Markdown and sending it to me or submitting a pull request, that would be great.
2.  T64 is not supported
3.  Not in this version

The good news is that I have released the next version of the hardware / firmware which supports (3) and have plans to document it better. I'll possibly look into T64. The Atmega / Arduino doesn't have sufficient flash and ram for new features and enhancements so I am moving to the ESP32 to provide this.

Check the project out here: https://github.com/sweetlilmre/TapuinoNext

lovrenco, 2022-01-18:
@sweetlilmre Are you sure you cannot add support for FW-RW to tap file?
Something like, now there are Play, Record, and you add "Play from", and when user selects that he must using forward and back keys find exact position in percent, and confirm it with "play" or "wait" option?

No need to provide save state functionality on the Tapuino device itself.

lovrenco, 2022-01-18:
@sweetlilmre OK, I tested this using Tapuino reloaded, EasyFlash3 with Retro Replay cart and Las ninja game.
When game loaded it showed 50% on tap file. I saved the game/backed up  RAM to floppy.
Turned on machine and loaded save state from floppy, and pressed Play on tapuino on the same file. Till restore was loaded tapuino came to 10% of tap file, and when game loaded from restore, tapuino stopped oading procedure.
I played first level and when I finished it, tapuino continued to increase percent. I had to wait till it reached 50% and then I heard second level loading music, few percent later. Second level loaded just fine.

So basically, there is no extra need for some hacks, id just Forward/Rewind function could be added Tapuino qould have one extra functionality.
I do not know how hard is to do it, and do we need some special programmer to load new firmware, or it can be done from SD card. This tapuino reloaded version does not have and microUSB slot that I can see.

sweetlilmre, 2022-01-20:
RAM and flash limits are almost at the max, it might be possible to squeeze this function (and accompanying UI) into the code, but it would be tight. At this point in time I don't have the bandwidth to look into this as I am concentrating on the Next, the code is open though so if someone wants to send in a pull request I'd look at merging it (the functionality can be found in the TapuinoNext source code).

Closed 2022-01-17.

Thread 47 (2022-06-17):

Load TAPs Hangs at 99%

preiner, 2022-06-17:
Running taupino 2.8

Repro Steps:

1) Choose Play
2) Scroll to desired TAP filename
3) Type in "Load"
4) See message to press play button
5) Press "Select" button on Taupuino
6) Progress indicator goes from 1% to 99% on left while displaying "M<spinner symbol" on right (no idea what M means)
7) See "Searching" message
8) See "Loading" message
9) See "Ready" message (while Taupino is at 99%)
10) Can list or run program just fine
11) Taupuino stuck at 99%. It will never complete. User must press "ABANDON"

sweetlilmre, 2022-06-18:
Hi,

This is by design. There is additional signal data in the TAP file after the program has loaded completely, so the Tapuino doesn't know that the TAP has finished. Code could be added to check the status of the motor line and complete if it was idle for "long enough" (sometimes the motor stops and starts during a normal load, so a motor stop can't be used as a definite marker of completing the load), but the ABORT key can be pressed to return to the menu. FYI the 'm' or 'M' symbol indicates that the tape motor is off 'm' or on 'M'.

preiner, 2022-06-18:
Can you goto 100% when you reach end of file?

Can you point me to docs on what all the various options do (machine, timings, finalize...)?
Does the machine option indicate what machine the tapuino is in or what machine made the TAP? I have seen the calculation based on the setting but the results running it seem to be the same regardless of setting

sweetlilmre, 2022-06-19:
Hi as I said, I could add code that would wait for a significantly long time and then complete, but that may break other functionality (multipart TAP loads). The machine option sets the specific signal timings (along with the video mode) and playback / recording mechanism for the machine in question (e.g. C16 uses 1/2 wave format). As the timings are relatively close, most work for most machines in the C64/PET/VIC20 group. As fas as docs go, there aren't any, but I will be adding docs to the evolution of this project: [https://www.github.com/sweetlilmre/TapuinoN](https://www.github.com/sweetlilmre/TapuinoN)ext

Closed 2022-06-18.

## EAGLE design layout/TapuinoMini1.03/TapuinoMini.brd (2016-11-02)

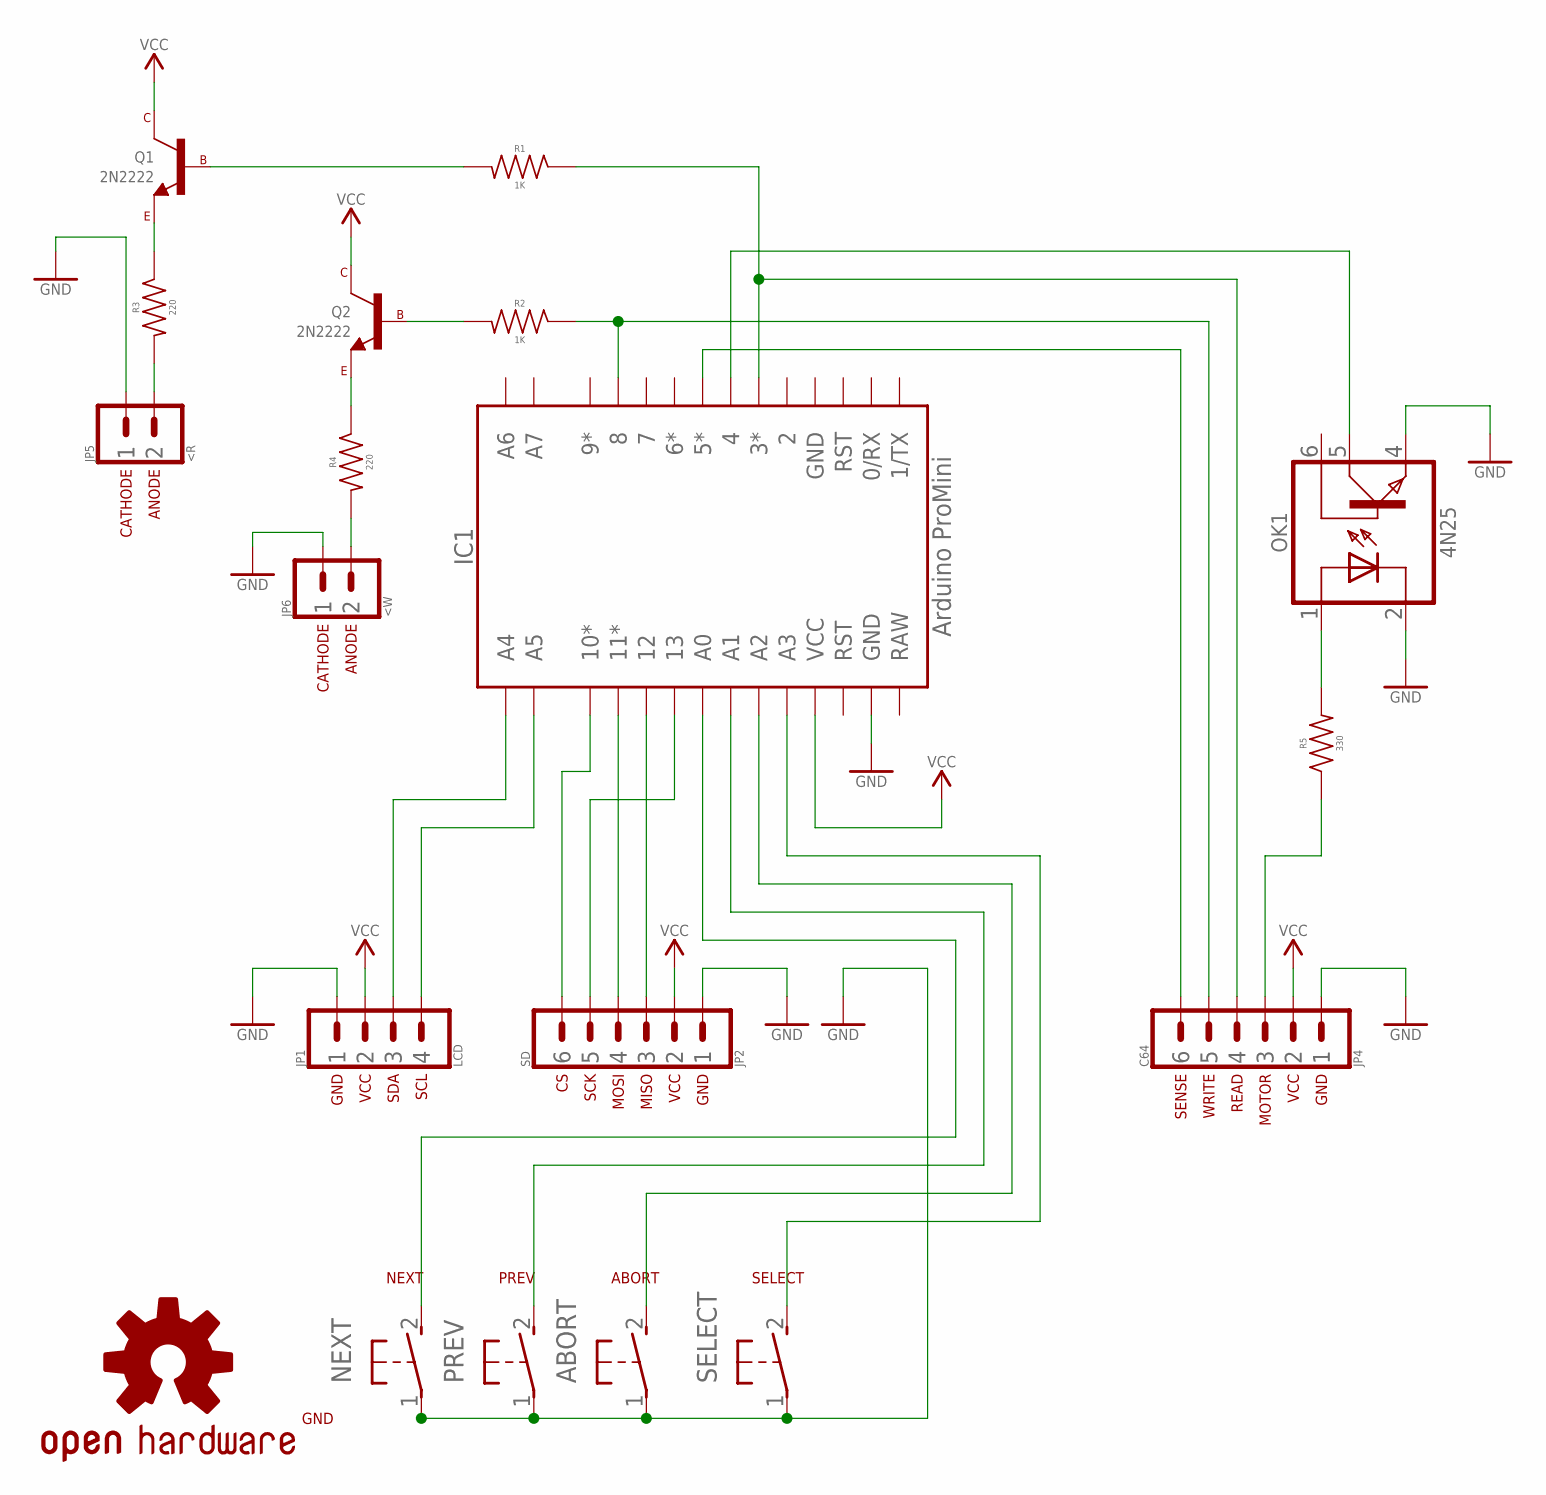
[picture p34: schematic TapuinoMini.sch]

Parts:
ABORT: 31-XX; B3F-31XX
IC1: Arduino ProMini; PROMINI_A
JP1: LCD; 1X04_SQR
JP2: SD; 1X06_SQR
JP4: C64; 1X06_SQR
JP5: <R; 1X02_SQR
JP6: <W; 1X02_SQR
LOGO1: OSHW-LOGOL; OSHW-LOGO-L
NEXT: 31-XX; B3F-31XX
OK1: 4N25; DIP06
PREV: 31-XX; B3F-31XX
Q1, Q2: 2N2222; TO-92
R1, R2: 1K; RESISTOR_PTH_0.3
R3, R4: 220; RESISTOR_PTH_0.3
R5: 330; RESISTOR_PTH_0.3
SELECT: 31-XX; B3F-31XX

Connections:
CS: IC1.10*, JP2.6
MISO: IC1.12, JP2.3
MOSI: IC1.11*, JP2.4
MOTOR2: OK1.1 (ANODE), R5.2
MOTOR3: IC1.4, OK1.5 (COLLECTOR)
unnamed: ABORT.2 (S), IC1.A2
unnamed: ABORT.1, IC1.GND@1 (GND), JP1.1, JP2.1, JP4.1, JP5.1, JP6.1, NEXT.1, OK1.2 (CATHODE), OK1.4 (EMITTER), PREV.1, SELECT.1
unnamed: IC1.VCC, JP1.2, JP2.2, JP4.2, Q1.3 (COLLECTOR), Q2.3 (COLLECTOR)
unnamed: JP4.3, R5.1
NEXT: IC1.A0, NEXT.2 (S)
PREV: IC1.A1, PREV.2 (S)
READ1: IC1.3*, JP4.4, R1.1
READ2: Q1.2 (BASE), R1.2
READ3: Q1.1 (EMITTER), R3.1
READ4: JP5.2, R3.2
S$1: IC1.5*, JP4.6
SCK: IC1.13, JP2.5
SCL: IC1.A5, JP1.4
SDA: IC1.A4, JP1.3
WRITE1: IC1.8, JP4.5, R2.1
WRITE2: Q2.2 (BASE), R2.2
WRITE3: Q2.1 (EMITTER), R4.1
WRITE4: JP6.2, R4.2

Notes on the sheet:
GND
VCC
SDA
SCL
SCK
MISO
MOSI
NEXT
PREV
ABORT
SELECT
MOTOR
READ
WRITE
SENSE
CATHODE
ANODE

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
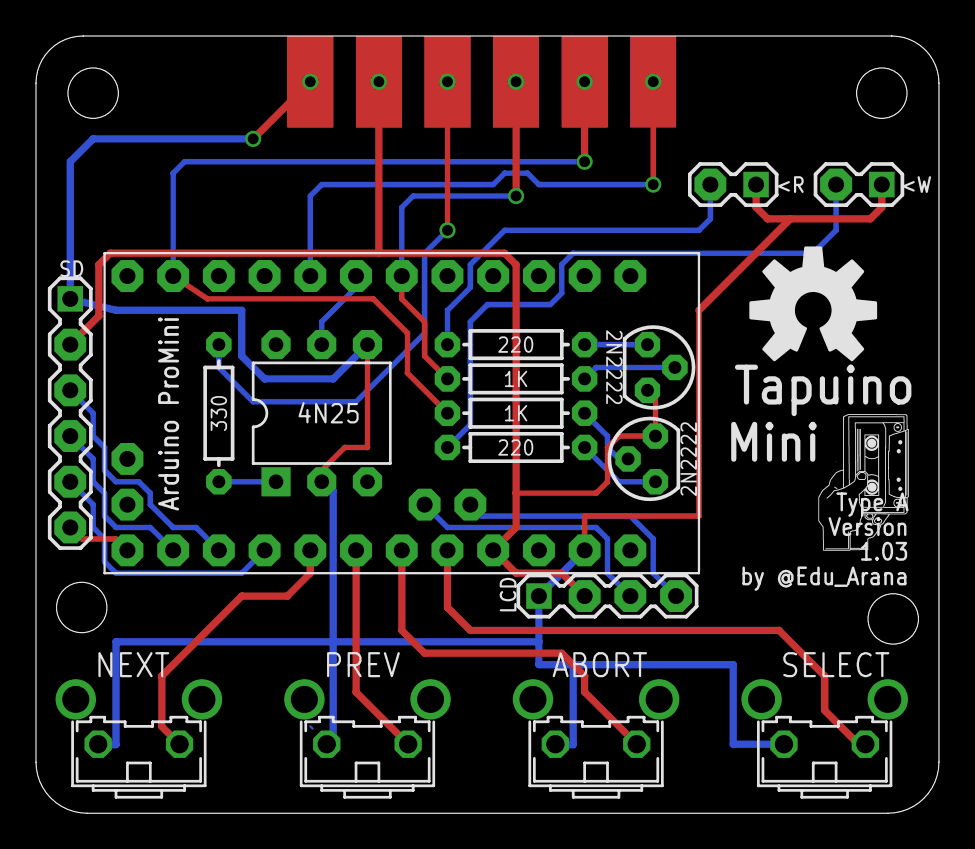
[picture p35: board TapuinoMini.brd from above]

Board: 2 copper layers, 50.2 x 43.2 mm, 18 parts (0 on the bottom side), 21 nets.

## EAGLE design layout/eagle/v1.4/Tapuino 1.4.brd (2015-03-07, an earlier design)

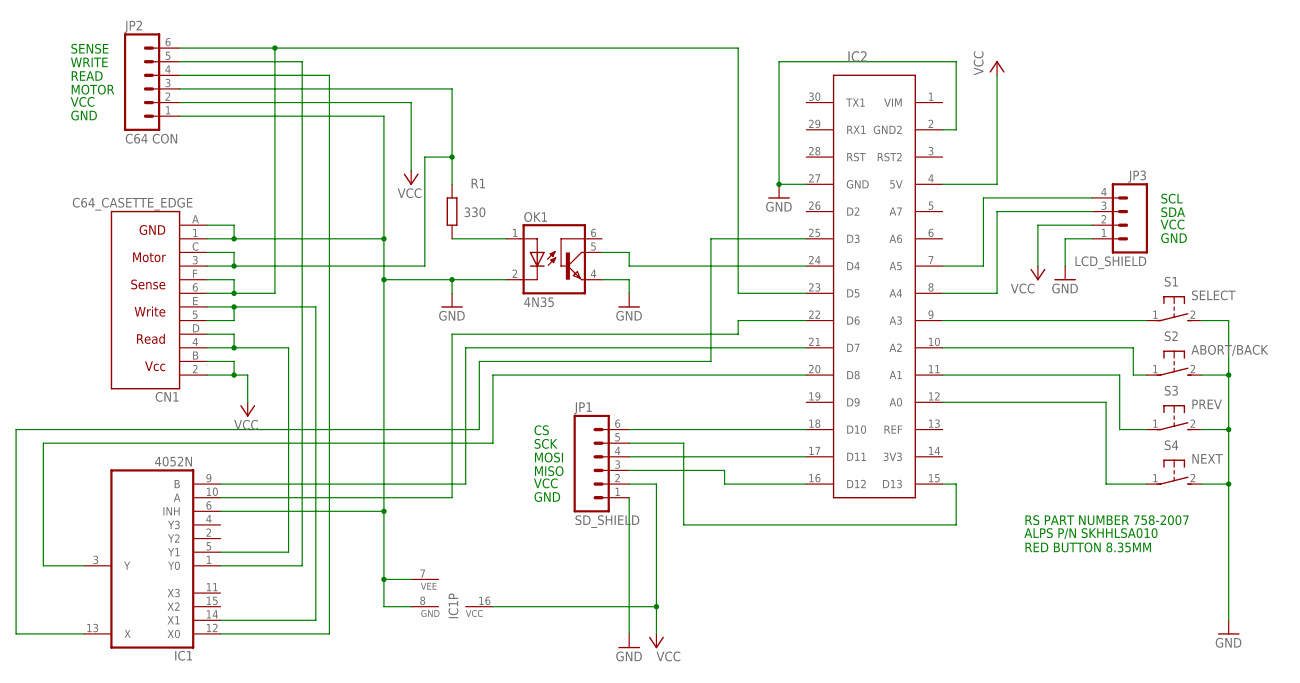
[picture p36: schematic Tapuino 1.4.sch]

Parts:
CN1: C64_CASETTE_EDGE; C64_CASSETTE
IC1: 4052N; DIL16
IC2: ARDUINO_NANO_V3; NANO_V3
JP1: SD_SHIELD; 1X06_LOCK_LONGPADS
JP2: C64 CON; 1X06_LOCK_LONGPADS
JP3: LCD_SHIELD; 1X04_LOCK_LONGPADS
OK1: 4N35; DIL06
R1: 330; 0207/10
S1: SELECT; B3F-31XX
S2: ABORT/BACK; B3F-31XX
S3: PREV; B3F-31XX
S4: NEXT; B3F-31XX

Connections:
GND: CN1.1 (GND1), CN1.A (GND2), IC1.6 (INH), IC1.7 (VEE), IC1.8 (GND), IC2.2 (GND2), IC2.27 (GND), JP1.1, JP2.1, JP3.1, OK1.2 (C), OK1.4 (EMI), S1.2 (S), S2.2 (S), S3.2 (S), S4.2 (S)
unnamed: IC2.16 (D12), JP1.3
unnamed: IC2.18 (D10), JP1.6
unnamed: IC2.15 (D13), JP1.5
unnamed: IC2.17 (D11), JP1.4
unnamed: IC2.7 (A5), JP3.4
unnamed: IC2.8 (A4), JP3.3
unnamed: IC2.9 (A3), S1.1
unnamed: OK1.1 (A), R1.1
unnamed: IC2.12 (A0), S4.1
unnamed: IC2.24 (D4), OK1.5 (COL)
unnamed: IC2.11 (A1), S3.1
unnamed: IC1.1 (Y0), JP2.5
unnamed: CN1.3 (MOTOR1), CN1.C (MOTOR2), JP2.3, R1.2
unnamed: IC1.3 (Y), IC2.20 (D8)
unnamed: IC1.12 (X0), JP2.4
unnamed: CN1.6 (SENSE1), CN1.F (SENSE2), IC2.23 (D5), JP2.6
unnamed: IC1.13 (X), IC2.25 (D3)
unnamed: CN1.4 (READ1), CN1.D (READ2), IC1.5 (Y1)
unnamed: IC1.9 (B), IC2.21 (D7)
unnamed: CN1.5 (WRITE1), CN1.E (WRITE2), IC1.14 (X1)
unnamed: IC1.10 (A), IC2.22 (D6)
unnamed: IC2.10 (A2), S2.1
VCC: CN1.2 (VCC1), CN1.B (VCC2), IC1.16 (VCC), IC2.4 (5V), JP1.2, JP2.2, JP3.2

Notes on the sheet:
SCK
MOSI
MISO
VCC
GND
SCL
SDA
SENSE
WRITE
READ
MOTOR
RS PART NUMBER 758-2007
ALPS P/N SKHHLSA010 RED BUTTON 8.35MM

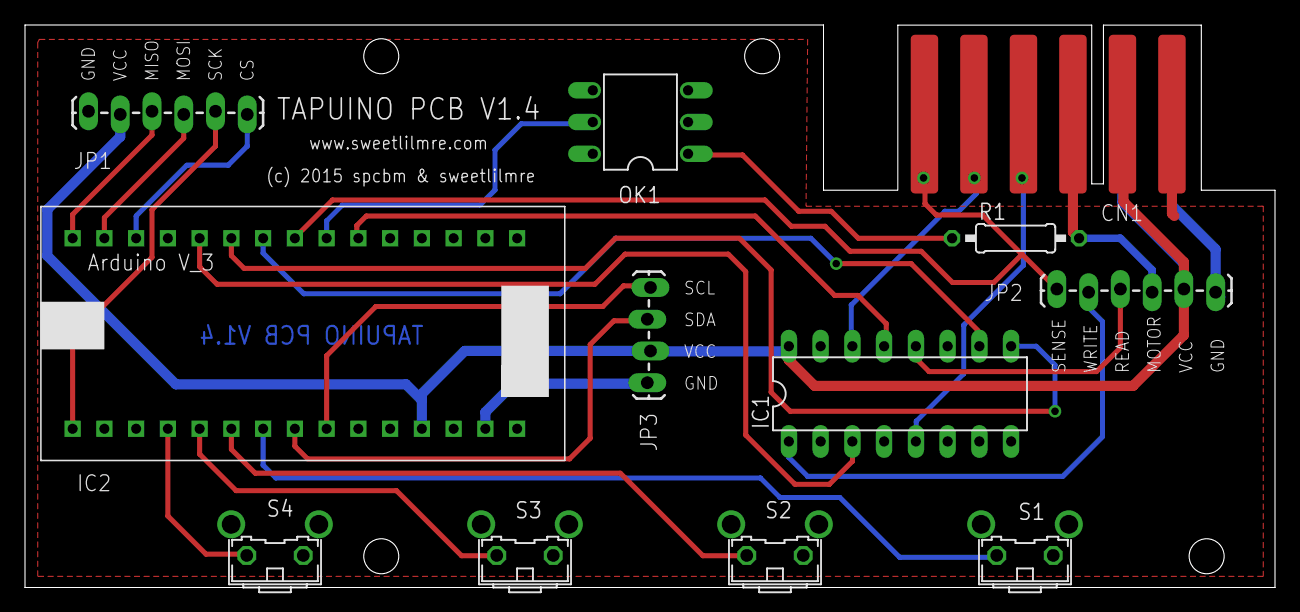
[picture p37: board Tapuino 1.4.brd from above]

Board: 2 copper layers, 100.0 x 45.0 mm, 12 parts (0 on the bottom side), 24 nets.

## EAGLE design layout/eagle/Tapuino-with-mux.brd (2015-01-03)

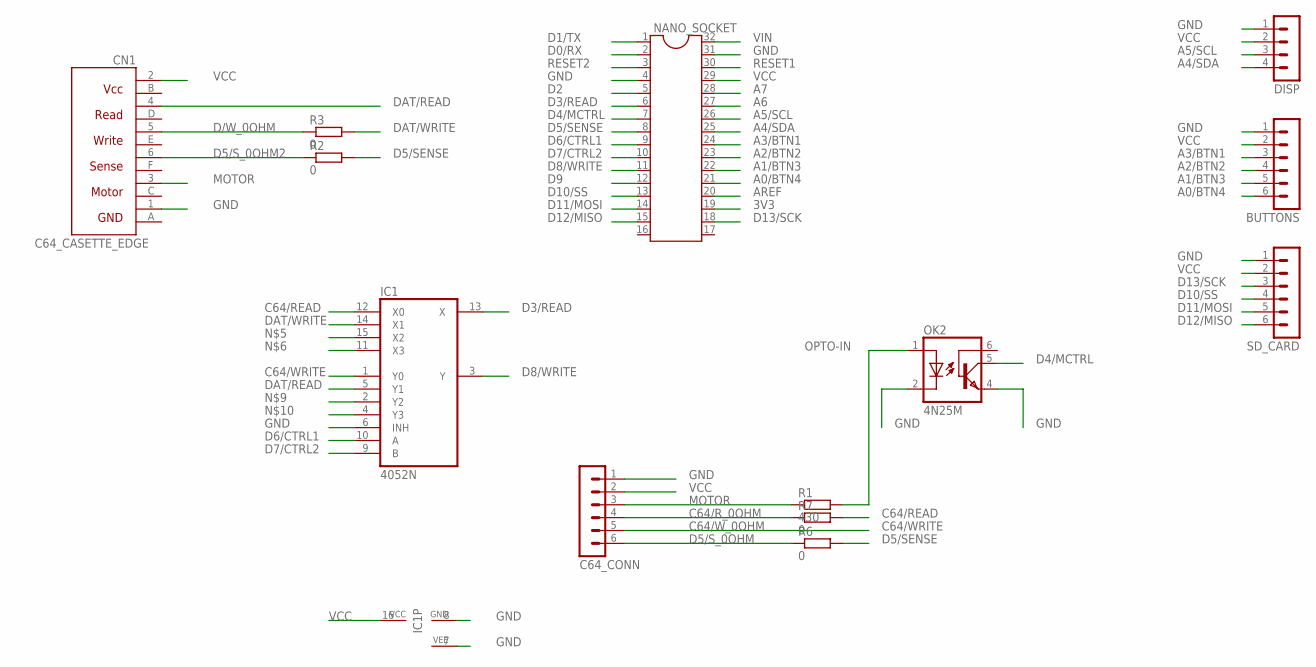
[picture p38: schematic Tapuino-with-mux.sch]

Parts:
BUTTONS: MA06-1
C64_CONN: MA06-1
CN1: C64_CASETTE_EDGE; C64_CASSETTE
DISP: MA04-1
IC1: 4052N; DIL16
NANO_SOCKET: DIL32
OK2: 4N25M; DIL06
R1: 430; 0207/10
R2, R3, R7: 0; 0207/10
R6: 0; 0207/5V
SD_CARD: MA06-1

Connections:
3V3: NANO_SOCKET.19
A0/BTN4: BUTTONS.6, NANO_SOCKET.21
A1/BTN3: BUTTONS.5, NANO_SOCKET.22
A2/BTN2: BUTTONS.4, NANO_SOCKET.23
A3/BTN1: BUTTONS.3, NANO_SOCKET.24
A4/SDA: DISP.4, NANO_SOCKET.25
A5/SCL: DISP.3, NANO_SOCKET.26
A6: NANO_SOCKET.27
A7: NANO_SOCKET.28
AREF: NANO_SOCKET.20
C64/READ: IC1.12 (X0), R7.2
C64/R_0OHM: C64_CONN.4, R7.1
C64/WRITE: IC1.1 (Y0)
C64/W_0OHM: C64_CONN.5
D0/RX: NANO_SOCKET.2
D1/TX: NANO_SOCKET.1
D2: NANO_SOCKET.5
D3/READ: IC1.13 (X), NANO_SOCKET.6
D4/MCTRL: NANO_SOCKET.7, OK2.5 (COL)
D5/SENSE: NANO_SOCKET.8, R2.2, R6.2
D5/S_0OHM: C64_CONN.6, R6.1
D5/S_0OHM2: CN1.6 (SENSE1), R2.1
D6/CTRL1: IC1.10 (A), NANO_SOCKET.9
D7/CTRL2: IC1.9 (B), NANO_SOCKET.10
D8/WRITE: IC1.3 (Y), NANO_SOCKET.11
D9: NANO_SOCKET.12
D10/SS: NANO_SOCKET.13, SD_CARD.4
D11/MOSI: NANO_SOCKET.14, SD_CARD.5
D12/MISO: NANO_SOCKET.15, SD_CARD.6
D13/SCK: NANO_SOCKET.18, SD_CARD.3
D/W_0OHM: CN1.5 (WRITE1), R3.1
DAT/READ: CN1.4 (READ1), IC1.5 (Y1)
DAT/WRITE: IC1.14 (X1), R3.2
GND: BUTTONS.1, C64_CONN.1, CN1.1 (GND1), DISP.1, IC1.6 (INH), IC1.7 (VEE), IC1.8 (GND), NANO_SOCKET.4, NANO_SOCKET.31, OK2.2 (C), OK2.4 (EMI), SD_CARD.1
MOTOR: C64_CONN.3, CN1.3 (MOTOR1), R1.1
OPTO-IN: OK2.1 (A), R1.2
RESET1: NANO_SOCKET.30
RESET2: NANO_SOCKET.3
VCC: BUTTONS.2, C64_CONN.2, CN1.2 (VCC1), DISP.2, IC1.16 (VCC), NANO_SOCKET.29, SD_CARD.2
VIN: NANO_SOCKET.32

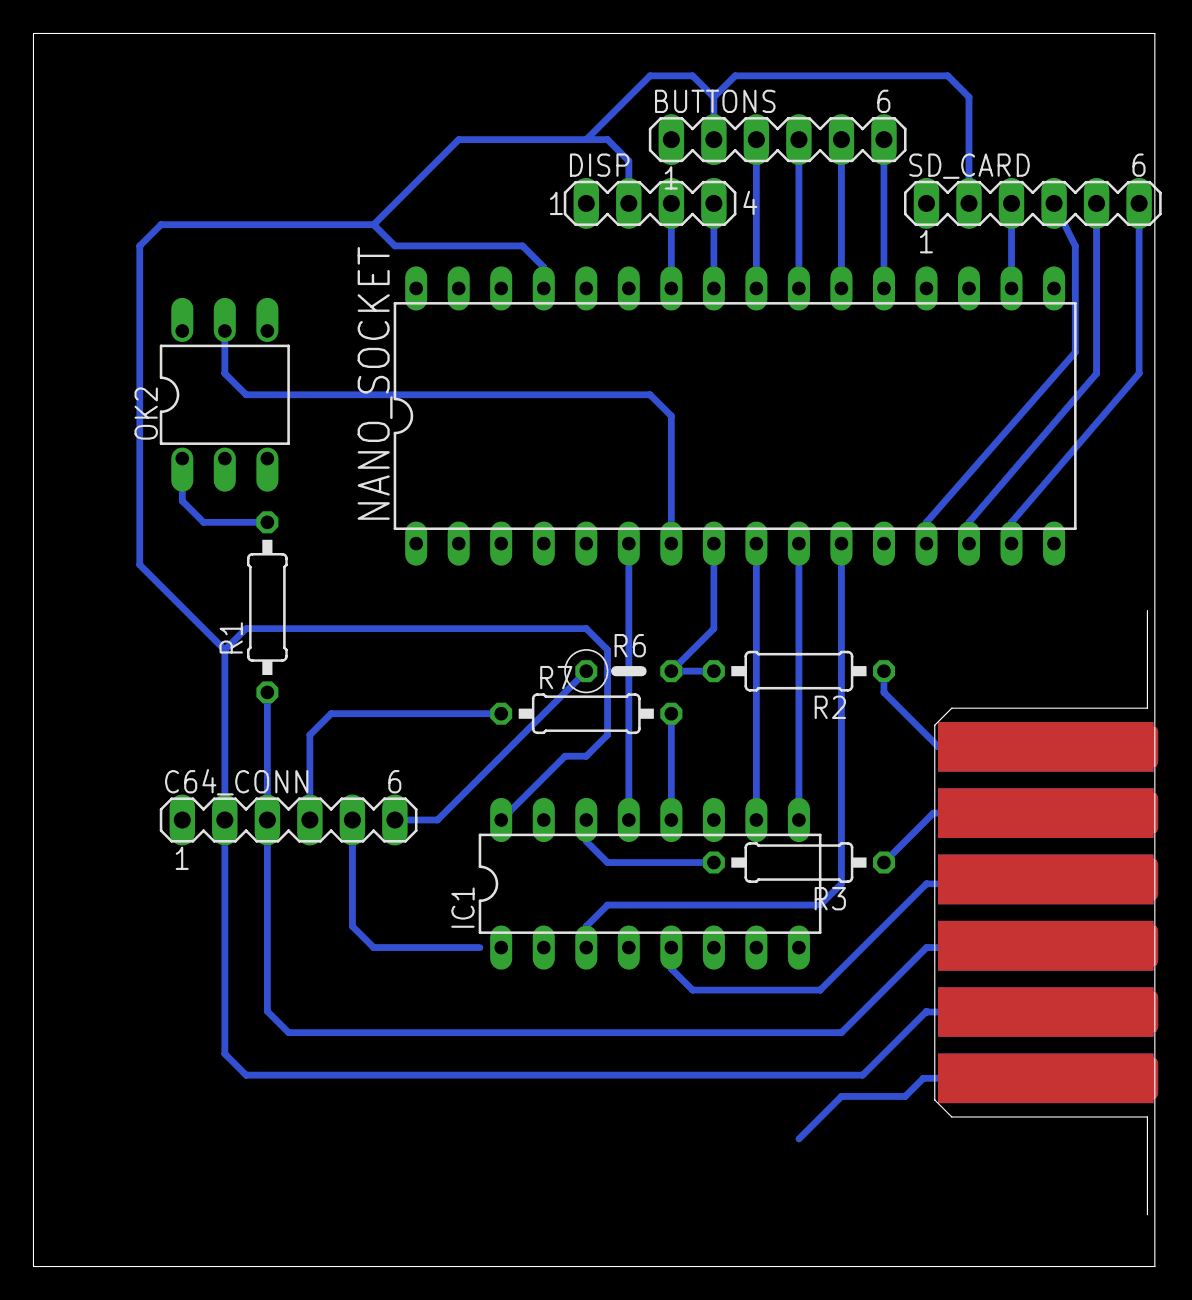
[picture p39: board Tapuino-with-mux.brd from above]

Board: 2 copper layers, 67.0 x 73.6 mm, 13 parts (1 on the bottom side), 27 nets.

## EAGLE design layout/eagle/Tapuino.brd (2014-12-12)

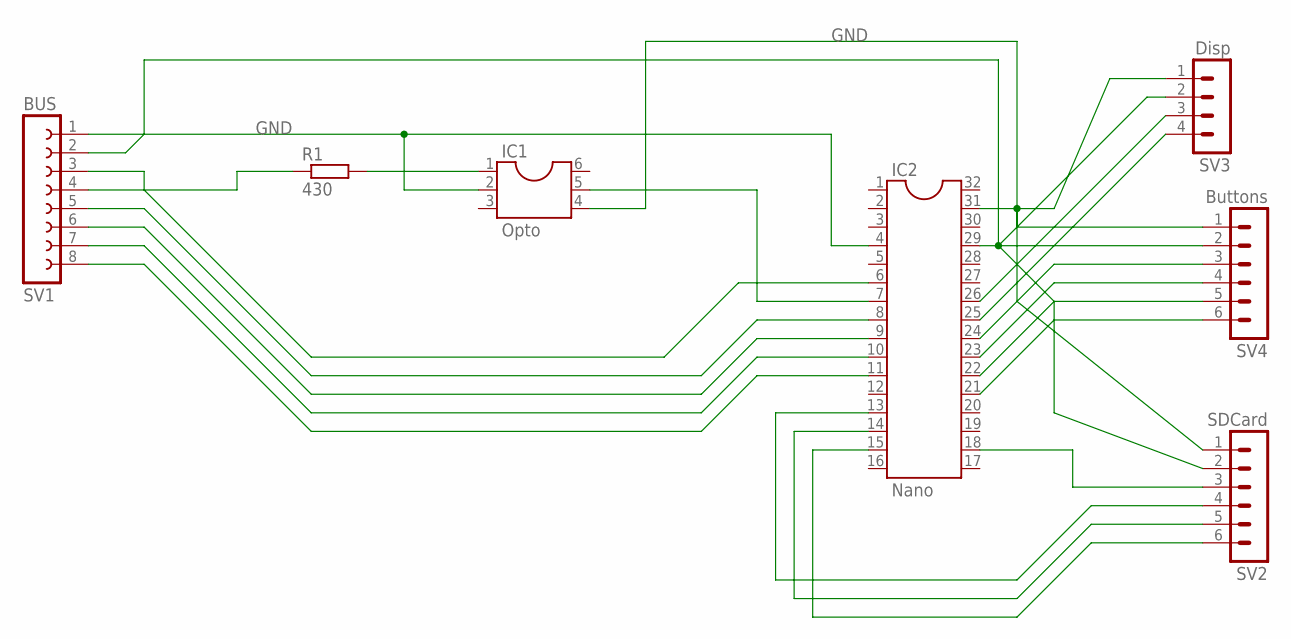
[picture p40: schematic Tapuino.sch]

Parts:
IC1: Opto; DIL06
IC2: Nano; DIL32
R1: 430; 0207/10
SV1: BUS; FE08
SV2: SDCard; MA06-1
SV3: Disp; MA04-1
SV4: Buttons; MA06-1

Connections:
GND: IC1.2, IC1.4, IC2.4, IC2.31, SV1.1, SV2.1, SV3.1, SV4.1
unnamed: R1.1, SV1.4
unnamed: IC2.29, SV1.2, SV2.2, SV3.2, SV4.2
unnamed: IC2.6, SV1.3
unnamed: IC1.1, R1.2
unnamed: IC1.5, IC2.7
unnamed: IC2.8, SV1.5
unnamed: IC2.9, SV1.6
unnamed: IC2.10, SV1.7
unnamed: IC2.11, SV1.8
unnamed: IC2.14, SV2.5
unnamed: IC2.15, SV2.6
unnamed: IC2.25, SV3.4
unnamed: IC2.13, SV2.4
unnamed: IC2.24, SV4.3
unnamed: IC2.26, SV3.3
unnamed: IC2.21, SV4.6
unnamed: IC2.23, SV4.4
unnamed: IC2.22, SV4.5
unnamed: IC2.18, SV2.3

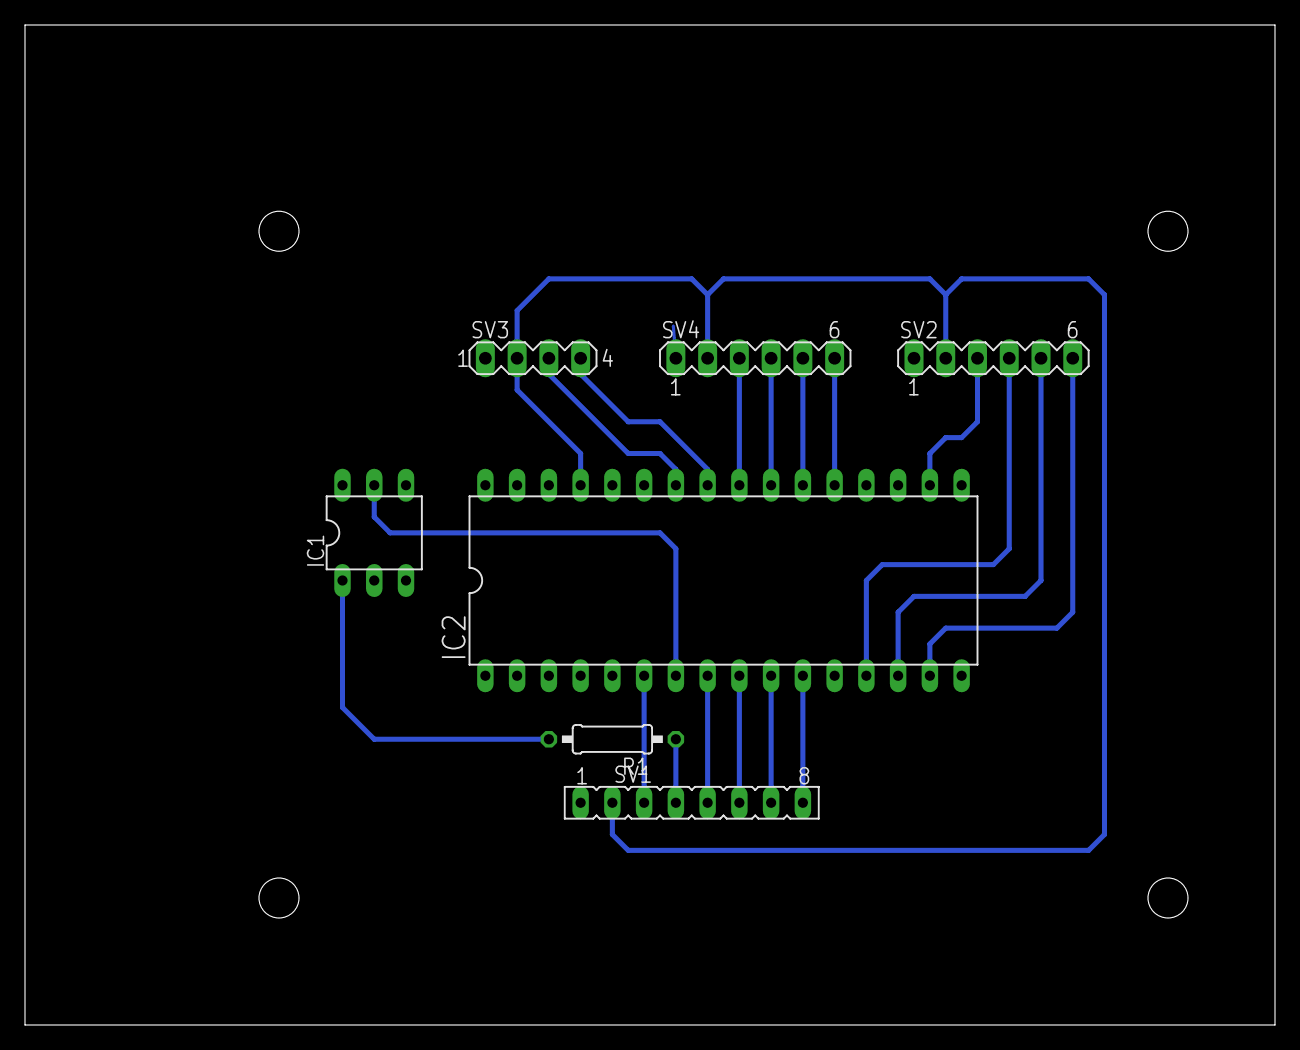
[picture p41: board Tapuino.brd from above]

Board: 2 copper layers, 100.0 x 80.0 mm, 7 parts (0 on the bottom side), 20 nets.

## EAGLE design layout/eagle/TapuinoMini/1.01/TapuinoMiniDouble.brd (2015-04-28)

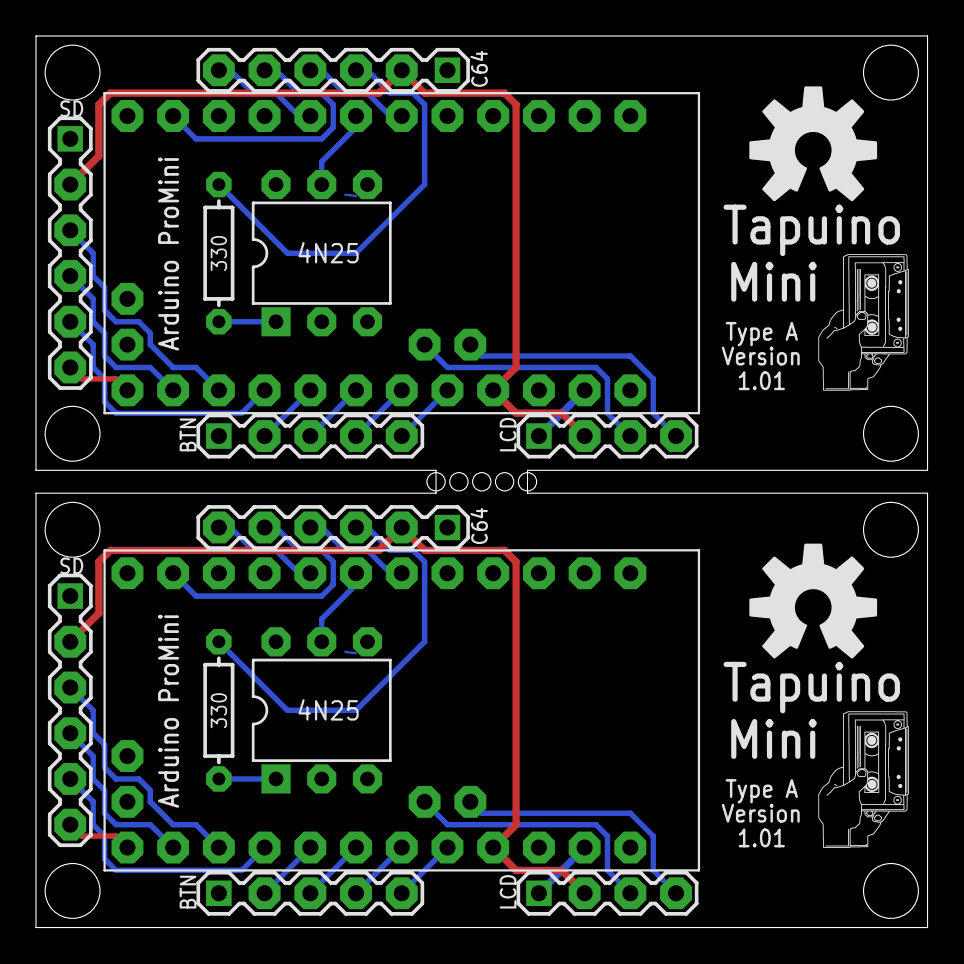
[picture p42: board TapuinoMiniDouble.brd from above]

Board: 2 copper layers, 49.5 x 49.5 mm, 16 parts (0 on the bottom side), 36 nets.

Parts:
IC1, IC2: Arduino ProMini; PROMINI_A
JP1, JP5: LCD; 1X04_SQR
JP2, JP6: SD; 1X06_SQR
JP3, JP7: BTN; 1X05_SQR
JP4, JP8: C64; 1X06_SQR
LOGO1, LOGO2: OSHW-LOGOL; OSHW-LOGO-L
OK1, OK2: 4N25; DIP06
R1, R5: 330; RESISTOR_PTH_0.3

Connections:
ABORT: IC1.A2, JP3.4
ABORT1: IC2.A2, JP7.4
CS: IC1.10*, JP2.6
CS1: IC2.10*, JP6.6
GND: IC1.GND@1, JP1.1, JP2.1, JP3.1, JP4.1, OK1.2, OK1.4
GND1: IC2.GND@1, JP5.1, JP6.1, JP7.1, JP8.1, OK2.2, OK2.4
MISO: IC1.12, JP2.3
MISO1: IC2.12, JP6.3
MOSI: IC1.11*, JP2.4
MOSI1: IC2.11*, JP6.4
MOTOR1: JP4.3, R5.1
MOTOR2: OK1.1, R5.2
MOTOR3: IC1.4, OK1.5
MOTOR4: JP8.3, R1.1
MOTOR5: OK2.1, R1.2
MOTOR6: IC2.4, OK2.5
NEXT: IC1.A0, JP3.2
NEXT1: IC2.A0, JP7.2
PREV: IC1.A1, JP3.3
PREV1: IC2.A1, JP7.3
READ1: IC1.3*, JP4.4
READ2: IC2.3*, JP8.4
SCK: IC1.13, JP2.5
SCK1: IC2.13, JP6.5
SCL: IC1.A5, JP1.4
SCL1: IC2.A5, JP5.4
SDA: IC1.A4, JP1.3
SDA1: IC2.A4, JP5.3
SELECT: IC1.A3, JP3.5
SELECT1: IC2.A3, JP7.5
SENSE: IC1.5*, JP4.6
SENSE1: IC2.5*, JP8.6
VCC: IC1.VCC, JP1.2, JP2.2, JP4.2
VCC1: IC2.VCC, JP5.2, JP6.2, JP8.2
WRITE1: IC1.8, JP4.5
WRITE2: IC2.8, JP8.5

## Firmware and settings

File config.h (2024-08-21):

#ifndef _CONFIG_H
#define _CONFIG_H

#include "config-user.h"

// thanks stack overflow: http://stackoverflow.com/questions/4301471/c-macro-to-test-if-more-than-one-defined
#if defined(LCD_USE_SSD1306_OLED_MODULE) + defined(LCD_USE_1602_LCD_MODULE) + defined(LCD_USE_SSD131X_OLED_MODULE) != 1
  #error Ether no or multiple LCD types defined! Have you created your config-user.h file?
#endif

#if defined(LCD_USE_SSD1306_OLED_MODULE)
  #if defined(LCD_SSD1306_128x64) + defined(LCD_SSD1306_128x32) != 1
    #error When using the SSD1306 module, define EITHER: LCD_SSD1306_128x64 or LCD_SSD1306_128x32 depending on your module type
  #endif
#endif

#if defined(TAPUINO_LANGUAGE_EN) + defined(TAPUINO_LANGUAGE_ES) + defined(TAPUINO_LANGUAGE_IT) + defined(TAPUINO_LANGUAGE_TR) + defined(TAPUINO_LANGUAGE_DE) != 1
  #error Either no or multiple languages defined! Have you created your config-user.h file?
#endif


#define LCD_BIT_RS          0    // Register select
#define LCD_BIT_RW          1    // Read / Write
#define LCD_BIT_EN          2    // Enable
#define LCD_BIT_BACKLIGHT   3    // Backlight
#define LCD_BIT_DATA0       4    // 4 bit data, bit 0
#define LCD_BIT_DATA1       5    // 4 bit data, bit 1
#define LCD_BIT_DATA2       6    // 4 bit data, bit 2
#define LCD_BIT_DATA3       7    // 4 bit data, bit 3
// LCD dimensions config
#define LCD_NUM_LINES       2    // number of display lines on the LCD
#define MAX_LCD_LINE_LEN    16   // max number of characters on a line

// Timing constant defaults, these will only apply until eeprom values are saved
#define TICKER_RATE         250  // milliseconds, granularity 10ms
#define TICKER_HOLD         1250 // milliseconds, ticker begin and end hold time, granularity 10ms
#define KEY_REPEAT_START    500  // milliseconds, granularity 10ms
#define KEY_REPEAT_NEXT     300  // milliseconds, granularity 10ms
#define REC_FINALIZE_TIME   2000 // milliseconds, granularity 10ms

// TWI for pullups
#define TWI_PORT            PORTC
#define TWI_PIN_SDA         4
#define TWI_PIN_SCL         5

// port definitions, change for different wiring
#define TAPE_READ_PORT      PORTD
#define TAPE_READ_DDR       DDRD
#define TAPE_READ_PIN       3
#define TAPE_READ_PINS      PIND
#define TAPE_READ_LOW()     TAPE_READ_PORT &= ~_BV(TAPE_READ_PIN)
#define TAPE_READ_HIGH()    TAPE_READ_PORT |=  _BV(TAPE_READ_PIN)

#define TAPE_WRITE_PORT     PORTB
#define TAPE_WRITE_DDR      DDRB
#define TAPE_WRITE_PINS     PINB
#define TAPE_WRITE_PIN      0

/* The Sense pin on the original Datassette is a physical switch that only grounds the line when pressed, it's left
 * floating when no keys are pressed. This means that the pin should be driven in an open-collector fashion, otherwise
 * it can create problems, in particular on the Plus/4 where the Sense line is shared with data pin 2 of the User Port.
 *
 * This could be compensated in hardware (put a diode in series, cathode to Arduino side) or in software, by taking
 * advantage of the way ATmega pins are configured, which is what we do here:
 * - To set sense "high" we set the pin to input mode, pin will go Hi-Z and basically float
 * - To set it low, we switch to output mode which will implicitly be low (PORTD defaults to 0 and we never touch it)
 */
#define SENSE_PORT          PORTD
#define SENSE_DDR           DDRD
#define SENSE_PIN           5
#define SENSE_ON()          SENSE_DDR |= _BV(SENSE_PIN)
#define SENSE_OFF()         SENSE_DDR &= ~_BV(SENSE_PIN)

#define MOTOR_PORT          PORTD
#define MOTOR_DDR           DDRD
#define MOTOR_PIN           4
#define MOTOR_PINS          PIND
#define MOTOR_IS_OFF()      (MOTOR_PINS & _BV(MOTOR_PIN))

#define CONTROL_PORT        PORTD
#define CONTROL_DDR         DDRD
#define CONTROL_PIN0        6
#define CONTROL_PIN1        7
#define CONTROL_SET_BUS0()  CONTROL_PORT &= ~(_BV(CONTROL_PIN0) | _BV(CONTROL_PIN1))
#define CONTROL_SET_BUS1()  { CONTROL_PORT &= ~_BV(CONTROL_PIN1); CONTROL_PORT |= _BV(CONTROL_PIN0); }

#define REC_LED_PORT        PORTD
#define REC_LED_DDR         DDRD
#define REC_LED_PIN         2
#define REC_LED_OFF()       REC_LED_PORT |= _BV(REC_LED_PIN)
#define REC_LED_ON()        REC_LED_PORT &= ~_BV(REC_LED_PIN)

 // comment this line if you are using HW1.0
#define KEYS_INPUT_PULLUP
#define KEYS_READ_PORT      PORTC
#define KEYS_READ_DDR       DDRC
#define KEYS_READ_PINS      PINC
#define KEY_SELECT_PIN      3
#define KEY_ABORT_PIN       2
#define KEY_PREV_PIN        1
#define KEY_NEXT_PIN        0

// debugging
//#define ENABLE_SERIAL

#endif

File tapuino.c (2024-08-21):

#include <avr/io.h>
#include <util/delay.h>
#include <avr/interrupt.h>
#include <avr/eeprom.h>
#include <inttypes.h>
#include <string.h>
#include <stdio.h>
#include <stdlib.h>

#include "version.h"
#include "integer.h"
#include "config.h"

#include "spi.h"
#include "ff.h"
#include "mmc.h"
#include "diskio.h"
#include "serial.h"
#include "comms.h"
#include "lcd_interface.h"
#include "lcdutils.h"
#include "memstrings.h"
#include "fileutils.h"
#include "menu.h"


typedef enum
{
  C64,
  VIC,
  C16,
} MACHINE_TYPE;

typedef enum
{
  PAL,
  NSTC,
} VIDEO_MODE;


// magic strings found in the TAP header, represented as uint32_t values in little endian format (reversed string)
#define TAP_MAGIC_C64      0x2D343643   // "C64-"  as "-46C"
#define TAP_MAGIC_C16      0x2D363143   // "C16-"  as "-61C"
#define TAP_MAGIC_POSTFIX1 0x45504154   // "TAPE"  as "EPAT"
#define TAP_MAGIC_POSTFIX2 0x5741522D   // "-RAW"  as "WAR-"

struct TAP_INFO {
  uint8_t version;              // TAP file format version:
                                // Version  0: 8-bit data, 0x00 indicates overflow
                                //          1: 8-bit, 0x00 indicates 24-bit overflow to follow
                                //          2: same as 1 but with 2 half-wave values
  uint8_t platform;             // Platform 0: C64
                                //          1: VIC
                                //          2: C16
  uint8_t video;                // Video    0: PAL 
                                //          1: NTSC
  uint8_t reserved;
  volatile uint32_t length;     // total length of the TAP data excluding header in bytes
  volatile uint32_t cycles;     // 
};

static struct TAP_INFO g_tap_info;

// the maximum TAP delay is a 24-bit value i.e. 0xFFFFFF cycles
// we need this constant to determine if the loader has switched off the motor before the tap has completed
// which would cause the code to enter an endless loop (when the motor is off the buffers do not progress)
// so we check during the buffer wait loop to see if we have exceeded the maximum delay time and exit if so.
#define MAX_SIGNAL_CYCLES     (g_cycle_mult_raw * 0xFFFFFF * 2)

// helper variables for the ISR and loader code

static volatile uint8_t g_read_index;           // read index in the 256 byte buffer
static volatile uint8_t g_write_index;          // write index in the 256 byte buffer
static volatile uint8_t g_signal_2nd_half;      // dual use flag: flag to indicate that the 2nd half of the signal should be output, or that recording has started
static volatile uint32_t g_total_timer_count;   // number of (AVR) cycles that the timer has been running for
static volatile uint8_t g_tap_file_complete;    // flag to indicate that all bytes have been read from the TAP
static volatile uint32_t g_tap_file_pos;        // current read position in the TAP (bytes)
static uint32_t g_pulse_length = 0;             // length of pulse in uS
static uint32_t g_pulse_length_save;            // saved length for 2nd half of the signal
static volatile uint32_t g_overflow;            // write signal overflow timer detection
static volatile uint32_t g_timer_tick = 0;      // timer tick at 100Hz (10 ms interval)

uint8_t g_machine_type = C64;
uint8_t g_video_mode = PAL;
static double g_cycle_mult_raw = 0;             // multiplier to convert a 24 bit TAP value into uS
static double g_cycle_mult_8 = 0;               // multiplier to convert an 8 bit TAP value into uS

volatile uint8_t g_invert_signal = 0;           // invert the signal for transmission/reception to/from a real Datasette

// all rate values are stored as milliseconds / 10.
// the global ticker runs at 100Hz which then maps 1-1 with these values
// So e.g. the key read function in comms.c: input_callback() is called by the global 100Hz timer, in this function g_key_repeat_next is used to determine the time between key repeats.
// each time this value is decremented 10 ms have passed, so a value of 100 is 100*10 = 1000 ms or 1 second repeat.

volatile uint16_t g_ticker_rate = TICKER_RATE / 10;
volatile uint16_t g_ticker_hold_rate = TICKER_HOLD / 10;
// volatile uint16_t g_key_repeat_start = KEY_REPEAT_START / 10;
volatile uint16_t g_key_repeat_next = KEY_REPEAT_NEXT / 10;
volatile uint16_t g_rec_finalize_time = REC_FINALIZE_TIME / 10;

volatile uint8_t g_rec_auto_finalize = 1;

volatile uint8_t g_is_paused = 0;

void setup_cycle_timing() {
  double ntsc_cycles_per_second;
  double pal_cycles_per_second;

  switch (g_machine_type)
  {
    case C64:
      ntsc_cycles_per_second = 1022272;
      pal_cycles_per_second  = 985248;
    break;
    case VIC:
      ntsc_cycles_per_second = 1022727;
      pal_cycles_per_second  = 1108404;
    break;
    case C16:
      ntsc_cycles_per_second = 894886;
      pal_cycles_per_second  = 886724;
    break;
  }
  
  switch(g_video_mode)
  {
    case PAL:
      g_cycle_mult_raw = (1000000.0 / pal_cycles_per_second);
    break;
    case NSTC:
      g_cycle_mult_raw = (1000000.0 / ntsc_cycles_per_second);
    break;
  }
  g_cycle_mult_8   = (g_cycle_mult_raw * 8.0);
}

uint32_t get_timer_tick() {
  return g_timer_tick;
}

// on rising edge of signal from C64
ISR(TIMER1_CAPT_vect) {
  uint32_t tap_data;

  if(g_signal_2nd_half) {                             // finished measuring 
    g_pulse_length = ICR1;                            // pulse length = ICR1 i.e. timer count
    g_pulse_length += (g_overflow << 16);             // add overflows
    g_pulse_length >>= 4;                             // turn raw tick values at 1/16th us into 1us i.e. divide by 16
    // start counting here
    g_overflow = 0;
    TCNT1 = 0;
    tap_data = g_pulse_length / g_cycle_mult_8;         // get the standard divided value
    
    if (tap_data == 0) {                              // safe guard
      tap_data++;
    }
    if (tap_data < 256) {                             // short signal
      g_fat_buffer[g_read_index++] = (uint8_t) tap_data;
      g_tap_file_pos++;
    } else {                                          // long signal
      tap_data = g_pulse_length / g_cycle_mult_raw;     // get the raw divided value (cycles)
      g_fat_buffer[g_read_index++] = 0;
      g_fat_buffer[g_read_index++] = (uint8_t) (tap_data & 0xff);
      g_fat_buffer[g_read_index++] = (uint8_t) ((tap_data & 0xff00) >> 8);
      g_fat_buffer[g_read_index++] = (uint8_t) ((tap_data & 0xff0000) >> 16);
      g_tap_file_pos += 4;
    }
  } else {
    // if this is the first time in, zero the count, otherwise the count starts at the high edge of the signal in the code above
    g_signal_2nd_half = 1;
    g_overflow = 0;
    TCNT1 = 0;
  }
  
}

ISR(TIMER1_OVF_vect){
  if (!MOTOR_IS_OFF()) {
    g_overflow++;
  }
}
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

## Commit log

2014-06-27 SPI Full speed fix and Timer rewrite (3rd time :()
2014-06-29 moving to indexed file selection and commit for crash recovery on my machine!
    [tapuino.c]
2014-06-30 Move lcd handling to utils, part of a slow bigger cleanup Added proper motor handling Made memstrings sharable
2014-07-02 Changed motor signal handling for new opto-coupler handling
2014-07-03 Removed length check timing, its still not working :(
    [tapuino.c]
2014-07-04 added button support and moved some config to config.h 2 line lcd now supported through config.h
2014-07-13 renames and cleanup. fixed exit condition for motor off timeout reduced display string length for 16x2 displays increased debounce time
    [tapuino.c]
2014-07-15 Added design files to layout folder Added write pin definition
    [tapuino.fzz]
2014-07-15 added button layouts
2014-07-17 oops! added missing break statement.
    [tapuino.c]
2014-07-23 added serial debugging to determine if I2C init is failing
    [tapuino.c]
2014-07-23 added I2C debugging statements over serial
2014-07-24 added I2C pullup init to fix I2C init issue on Funduino LCM1602 board
    [config.h, tapuino.c]
2014-07-27 Fixed SD timeout handling for write Moved menu ui and handling into separate code files Added initial write code, doesn't work yet
    [mmc.c, tapuino.c]
2014-07-27 fixed write offset issues for TAP writing (length is now correct) fixed port config for write pin
    [config.h, tapuino.c]
2014-07-27 First successful write code!!!! various fixes serial baud rate changed to 57600
    [config.h, tapuino.c]
2014-07-28 updated Fritizing file and image
    [tapuino.fzz]
2014-08-03 Added fix for long loader and possibly multiload games
    [tapuino.c]
2014-08-04 Moved all dodgy timing to use system 10ms timer Added key repeat functionality Cleaned up comms, serial is removed now
2014-08-07 LCD configuration now in config.h for I2C expander bit mapping
2014-08-11 Added short and long key press detection code Bug fix: added missing sense signal OFF after record
    [tapuino.c]
2014-08-11 fix for blank entries after a recording removed pointless memstring optimization removed unnecessary memstrings
    [tapuino.c]
2014-08-20 Fixed menu flow for recording Fixed missing zero terminator in lcdutils when writing the status line Reworded some strings Added initial support for signal inversion (only playback and hardcoded atm)
    [tapuino.c]
2014-08-21 Changed all config.h timing value to millisecond Fixed filename_ticker for millisecond values and line length Made strings less verbose to save flash space Added basic option value code
    [config.h]
2014-08-22 FIX: forgot to mark g_invert_signal extern...
    [tapuino.c]
2014-08-23 FIX: Ticker bug where filename wouldn't start at first character
    [tapuino.c]
2014-10-12 Control line code for MUX switching Fixed PROGMEM references for Atmel Studio Added Atmel Studio project files Added new and updated schematic and fritzing files
    [tapuino.fzz]
2014-12-08 fixed casing for lcd.h include in lcd.c
    [lcd.c]
2014-12-12 Added Tapuino Eagle files
    [Tapuino.brd, Tapuino.sch]
2015-01-03 added rev2 board with mux Eagle files
    [Tapuino-with-mux.brd, Tapuino-with-mux.sch]
2015-01-03 Minor changes to mux board
    [Tapuino-with-mux.brd]
2015-01-20 Tapuino 1.2. board layout added
    [Tapuino 1.2.brd, Tapuino 1.2.sch]
2015-01-20 Added spcbm 1.2 board, removed mine
    [Tapuino 1.2 con botones.brd, Tapuino 1.2 con botones.sch]
2015-01-20 minor cleanup for spcbm 1.2
    [Tapuino 1.2 con botones.brd]
2015-01-24 removed url until I know what the official one is
    [Tapuino 1.2 con botones.brd]
2015-02-14 Update config.h
    added config option for HW 2.0 boards
2015-02-14 Update comms.c
    added key support for HW 2.0 board
2015-02-14 Fixed 'command leakage' when playback was aborted which caused the menu to go up a dir. Some minor cleanup of tabs and indentation
    [config.h, tapuino.c]
2015-02-25 Special handling for TAP format 0. Fixed command leakage from recording mode
    [tapuino.c]
2015-03-07 Made V2 hardware (internal pullups) the default behaviour Made serial compilation conditional via config.h
    [Tapuino 1.5.brd, Tapuino 1.5.sch]
2015-03-07 Cleaning up layout folders
    [1602 QAPASS LCD Template -0.5.brd, Tapuino 1.5.brd, Tapuino 1.5.sch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]
2015-03-07 More cleanup on layout
    [Tapuino 1.2 con botones.brd, Tapuino 1.2 con botones.sch, Tapuino-with-mux.brd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]
2015-03-07 added missing 1.4 board files
    [Tapuino 1.4.brd, Tapuino 1.4.sch]
2015-03-16 added missing and updated r2 images
    [tapuino-r2.fzz]
2015-03-22 Rework of the LCD drivers to allow for support for various other I2C based displays Fix for button board layout
    [config.h, dsip_lcd.c, tapuino.c]
2015-03-27 Fixed bug where recording would not work on a blank formatted SD Card i.e. there had to be at least one file / folder on the card Made creation of recorded folder part of startup.
    [tapuino.c]
2015-03-27 reverted to standard LCD module
    [config.h]
2015-04-02 Added Mini design files by ozayturay
    [TapuinoMini.brd, TapuinoMini.sch, TapuinoMiniDouble.brd]
2015-04-05 Added: initial OLED driver refactored code to use tap header and be aware of C16 TAP files (support is not complete yet)
2015-04-05 Fix: various warnings and line ending consistency
    [dsip_lcd.c, tapuino.c]
2015-04-16 Update memstrings.c-it
    better translation, revert "salvataggio" to "record" for compatibility, italians c64 fan does know what "record" mean :D
2015-04-18 doubled signal length for half-wave TAP format at 2Mhz timer
2015-04-20 Bugfix for Format 2 support (half-waves) Work around for TAPs with bizarre length values in the header Clean-up of cycle handling for different machines
    [config.h, tapuino.c]
2015-04-28 Updated TapuinoMini Eagle design files in layout folder.
    [TapuinoMini.brd, TapuinoMini.sch, TapuinoMiniDouble.brd]
2015-05-04 Update tapuino.c
    fixed save header for c16 tap format compatibility ($02 @ $0D)
    [tapuino.c]
2015-05-24 Moved user config to config-user.h with config-user.h.example as a template moved language files and added preprocessor guards to allow for configurable language Fixed some compiler warnings for miss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
    [config.h, disp_LCD_HD44780.c, disp_oled_ssd1306.c]
2015-05-25 Added Pause function. SELECT button will toggle pause mode, 'P' will be displayed on the LCD
2015-06-05 added recording LED config and code
2015-08-16 Added Auto Finalize option fixed option handling in menu.c to remember last select option when exiting from a specific option menu
    [tapuino.c]
2015-08-17 Fixed translation Fixed complete message
    [tapuino.c]
2015-08-19 Fixed bug when ABORT was pressed in Select Mode menu Potential fix to prevent LONG pauses when recording using manual finalize mode with multiple blocks and motor stops (rainbow islands masterings so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
    [tapuino.c]
2016-09-23 Add makefile utilizing arduino-builder and avrdude
2016-11-02 Added Tapuino Mini schematics
    [TapuinoMini.GBL, TapuinoMini.GBO, TapuinoMini.GBP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]
2016-11-02 updated readme to reflect the location of the Tapuino Mini schematics
2017-12-09 minor fix to 1602 OLED module to add a small delay post I2C init for init stability version bump
    [disp_oled_ssd1306.c]
2017-12-11 Fixed SSD131x driver compile fail (rename of i2cmster.h to i2c_master.h)
    [disp_oled_SSD131x.c]
2017-12-25 adding gitattibutes file in an attempt to have the repo correctly classified
    [disp_oled_ssd1306.c]
2017-12-26 changed READ and WRITE lines to LOW to avoid lighting LEDs on aranet board
    [tapuino.c]
2018-01-25 added switchable font size for SSD1306 oled, defined by LCD_SSD1306_BIG_FONTS in config-user.h
2022-01-27 Fixed uninitialized variable check (br) in play_file() and initial buffer read in verify_tap() Moved FatsFS buffer into flash storage Commented unused config setting g_key_repeat_start Changes sugges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
    [tapuino.c]
2023-02-17 Added 3d printable enclosure (#49)
    * Added enclosuer STL files for 3d printing
    * Added enclosuer STL files for 3d printing
    * Files structure updated
    * README updated
    * README updated
    * README updated
    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
    [C=64 Datassette connector - base.stl, C=64 Datassette connector - lid.stl, Display lid.stl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]
2024-08-21 Handle Sense pin in an open-collector fashion (#52)
    * Handle Sense pin in an open-collector fashion
    * Fix description
    [config.h, tapuino.c]

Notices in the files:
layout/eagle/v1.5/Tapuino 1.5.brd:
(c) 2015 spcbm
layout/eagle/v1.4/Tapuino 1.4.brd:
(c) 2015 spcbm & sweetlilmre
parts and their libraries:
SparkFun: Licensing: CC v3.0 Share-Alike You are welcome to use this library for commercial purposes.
